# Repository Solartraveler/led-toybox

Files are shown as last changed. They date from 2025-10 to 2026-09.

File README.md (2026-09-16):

# LED Spiel

## Idea

Add some RGB LEDs in a box with sound. Fun for kids.

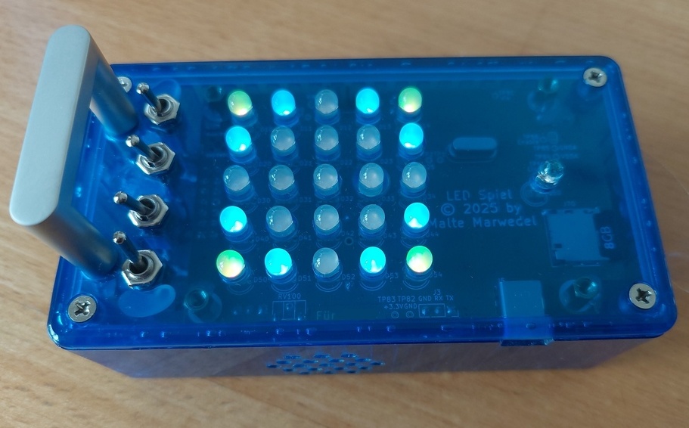
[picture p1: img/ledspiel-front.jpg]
Box in blue case


## Features

- 5x5 RGB LEDs

- Mono sound output

- Up to 7 inputs for buttons

- Measure brightness of environment to adjust LED brigtness

- IR receiver allows every remote control to become an extra toy

- Runs with two rechargeable NIMH AAA batteries. Non rechargeable ones work too.

- Slow charge over USB (~80mA). Can be disabled for non rechargeable batteries.

- SD card for storing sound (mp3 files) and LED sequences

- SD card file exchange and firmware upload over USB

- The STM32F405 MCU is fast enough for mp3 decoding

- Costs for all parts is ~95€.

## Status

The PCB is soldered, the case is complete, the software for the toy works, but is incomplete.

Two push buttons are on the left side, if one is pressed during power up, the device enters DFU firmware download mode.

Four switches are there for selecting songs.

Some animations are available.

Missing featues:

- Data exchange over USB mass storage is slow

- The IR receiver is currently unused.

## History

Planning...

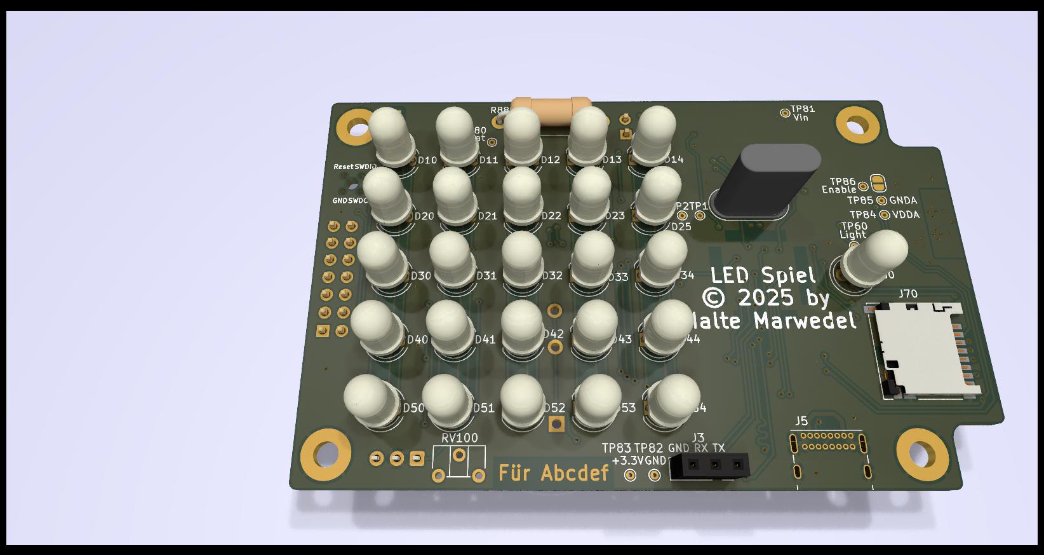
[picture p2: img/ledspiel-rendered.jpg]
PCB rendered


Soldering and debugging...

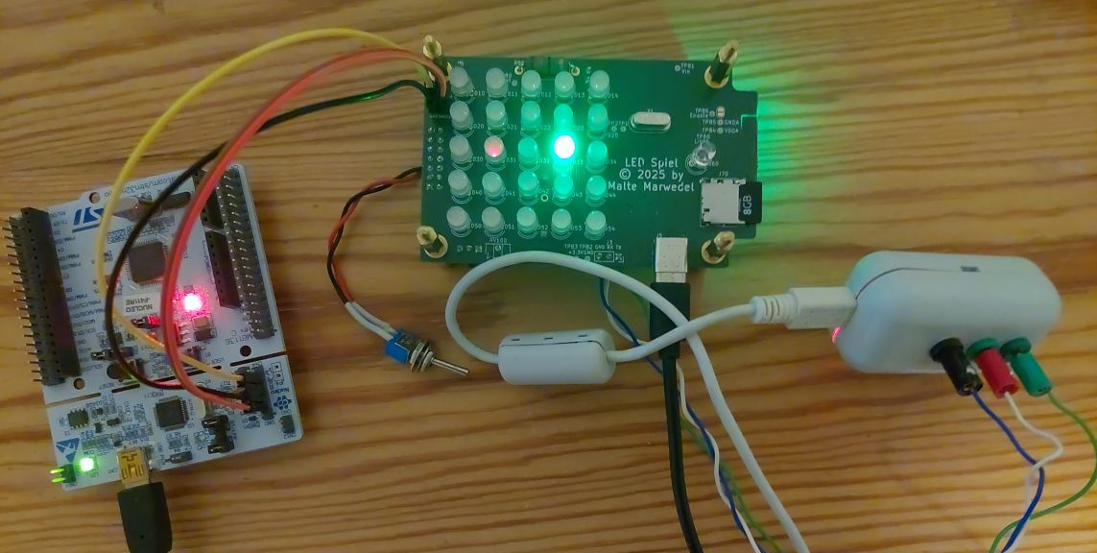
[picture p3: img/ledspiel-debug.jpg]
PCB with debug connection


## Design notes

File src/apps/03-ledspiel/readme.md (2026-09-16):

The ledspiel firmware

Implements USB mass storage if connected to USB.
Otherwise its an mp3 player with funny light effects.

The USB mass storage is a modified copy of
[06-usb-mass-storage](https://github.com/Solartraveler/UniversalboxArm/tree/a2017e5d17217898de555d77526e7ae967745359/src/apps/06-usb-mass-storage)

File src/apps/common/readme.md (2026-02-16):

# Shared files for the ARM processor #

## algorithm ##

Useful platform independend algorithm by the author of this project.

Files taken from [UniversalboxARM](https://github.com/Solartraveler/UniversalboxArm/tree/a2017e5d17217898de555d77526e7ae967745359/src/common/algorithm) commit #a2017e5d17217898de555d77526e7ae967745359.

License: BSD 3-Clause

## CMSIS ##
CMSIS header files from ARM and ST

License: Apache 2.0

Taken from STM32Cube_FW_F4_V1.28.3

and

STM32Cube_FW_F4_V1.25.2

# fatfs #
Fat filesystem from (http://elm-chan.org/fsw/ff/00index_e.html) version 0.14b.

License: BSD 1-Clause

# jsmn
Json parser from (https://github.com/zserge/jsmn) version 1.1.0

License: MIT

# ledspiellib

Files from the author of this project

Files are simply copied from [UniversalboxARM](https://github.com/Solartraveler/UniversalboxArm/tree/a2017e5d17217898de555d77526e7ae967745359/src/apps/common/boxlib) commit #a2017e5d17217898de555d77526e7ae967745359.
And where needed adapted to the STM32F405 and LedSpiel PCB pin connections.

License: BSD 3-Clause

# libmad
Libmad - MPEG audio decoder library

License: GPL v2 or newer

Taken from GIT [version 0.16.4 commit ee7c3cdd4361b7f7c7da52fa3ba9f76cc35230a9](https://codeberg.org/tenacityteam/libmad/releases/tag/0.16.4)

# lwip
Just for md5sum calculation.

Files taken from [LwIP](https://savannah.nongnu.org/projects/lwip/) version 2.1.3.

License: BSD 3-Clause

## shared-init
Most files are from ST. Linker scripts and init assembly routines.

License: Apache 2.0 and BSD 3-Clause

appInterface.h, stm32f4xx_hal_msp.c, system_stm32f4xx.c, and main.c are taken from
[UniversalboxARM](https://github.com/Solartraveler/UniversalboxArm/blob/a2017e5d17217898de555d77526e7ae967745359/src/apps/common/shared-init/) commit #a2017e5d17217898de555d77526e7ae967745359.

stm32f405-LedSpielV1/main.h is a modified file taken from
[UniversalboxARM](https://github.com/Solartraveler/UniversalboxArm/blob/a2017e5d17217898de555d77526e7ae967745359/src/apps/common/shared-init/stm32f411-nucleo/main.h) commit #a2017e5d17217898de555d77526e7ae967745359.
The modification is mostly CubeMX generated.

stm32f405-LedSpielV1/stm32f4xx_hal_conf.h is taken from
[UniversalboxARM](https://github.com/Solartraveler/UniversalboxArm/blob/a2017e5d17217898de555d77526e7ae967745359/src/apps/common/shared-init/stm32f411-nucleo/stm32f4xx_hal_conf.h) commit #a2017e5d17217898de555d77526e7ae967745359.

## stm32f4xx_HAL_Driver ##
Files from ST.

License: BSD 3-Clause

Taken from STM32Cube_FW_F4_V1.28.3

## libusb_stm32 ##
Usb communication library

License: Apache 2.0

Most files (but one) are taken from
[Libusb_stm32](https://github.com/dmitrystu/libusb_stm32) commit #396c2c50ad330b522104d0565525a7350e486fb9

The stm32_compat.h file is based on:
[stm32h](https://github.com/dmitrystu/stm32h/blob/7e854b1938c6ba5b4163b08de7842e406b5c5fcb/stm32.h) commit #7e854b1938c6ba5b4163b08de7842e406b5c5fcb

License: MIT

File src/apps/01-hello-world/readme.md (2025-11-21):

A simple function test

Prints a message over the UART and let some LEDs flash some patterns.

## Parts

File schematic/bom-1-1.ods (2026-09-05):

BOM LED Spiel | Version 1.1
ID | Name | Number | Reichelt Order No | TME Order No | Price | Sum Price | Notes | 3.1V Low voltage variant (should save ~10% consumption)
C1, C2, C71, | 22pF Unpolarized capacitor | 3 | NPO-G0805 22P |  | 0.02 € | 0.06 €
C3, C4, | 10pF Unpolarized capacitor | 2 | NPO-G0805 10P |  | 0.02 € | 0.04 € | C3 and C4 are only required if Y2 is equipped
C60, C70, C81, C86, C87, C92, C93, C101, C102, | 2.2µF Unpolarized capacitor | 9 | GRM21BR71E225K |  | 0.03 € | 0.27 €
C80, C82, C83, C84, | 10µF Unpolarized capacitor | 4 | GRM21BZ71E106K |  | 0.11 € | 0.44 €
C85, C88, C89, C90, C91, C100, | 100nF Unpolarized capacitor | 6 | KEM X7R0805 100N |  | 0.02 € | 0.12 €
C103, | 18nF Unpolarized capacitor | 1 | WAL 0805B183K500 |  | 0.04 € | 0.04 € | Optional
D10, D11, D12, D13, D14, D20, D21, D22, D23, D25, D30, D31, D32, D33, D34, D40, D41, D42, D43, D44, D50, D51, D52, D53, D54, | LED_RKBG RGB LED, red/cathode/blue/green | 25 | KBT L-154A4SURKQ |  | 0.80 € | 20.00 €
D80, D82, | SK14 Schottky diode | 2 | SK 14 DIO |  | 0.05 € | 0.10 €
D81, D83 | LED Light emitting diode green | 2 | 0805G3C-KHC-B |  | 0.19 € | 0.38 € | Actually any preferred color, red, green or blue can be used
D85, | LED Light emitting diode red | 1 | LS R976 |  | 0.04 € | 0.04 € | Actually any preferred color, red, green or blue can be used
D84, | BAT54C Schottky diode | 1 | BAT 54C SMD |  | 0.03 € | 0.03 €
F80, | 250mA Fuse | 1 | SMD-HASF 0,25A |  | 1.10 € | 1.10 € | Might be increased to 500mA depending on real consumption
J1, | Keys Generic connector, double row, 02x07, odd/even pin numbering scheme (row 1 odd numbers, row 2 even numbers), script generated (kicad-library-utils/schlib/autogen/connector/) | 1 | SL 2X10G 2,54 |  | 0.13 € | 0.13 €
J2, | SWD Debug Harwin M20-7810245 | 1 | --- | --- |  | 0.00 € | Optional
J3, | USART Debug Generic connector, single row, 01x03, script generated (kicad-library-utils/schlib/autogen/connector/) | 1 | MPE 094-1-003 |  | 0.14 € | 0.14 €
J5, | USB_C_Receptacle_USB2.0 USB 2.0-only Type-C Receptacle connector | 1 | --- | USB4085-GF-A | 0.88 € | 0.88 €
J70, | Micro_SD_Card_Det Micro SD Card Socket with card detection pins | 1 | --- | DM3D-SF/C | 1.90 € | 1.90 €
J80, JP1 | Battery Generic connector, Recharge Jumper, single row, 01x02, break off from J1 | 0 | SL 2X10G 2,54 |  | 0.13 € | 0.00 €
JP1, | Jumper | 1 | JUMPER 2,54 SW |  | 0.02 € | 0.02 €
L1, | 4.7µH Inductor, 1.5A | 1 | L-PISG 4,7µ |  | 0.99 € | 0.99 €
L2, | 1µH Inductor, 370mA | 1 | L-1008AS 1,0µ |  | 0.25 € | 0.25 €
LS100, | Speaker 0.2W (0.3W peak), 155070 | 1 | AL-30P |  | 2.89 € | 2.89 € | With the testpin TP100, the 0.1W AL23-P variant can be used as alternative
Q10, Q11, Q12, Q13, Q14, Q80, Q82, | BSS138 50V Vds, 0.22A Id, N-Channel MOSFET, SOT-23 | 7 | BSS 138P NXP |  | 0.06 € | 0.42 €
Q60, | SFH300-3/4 NPN phototransistor, collector/emitter | 1 | SFH 300-3/4 |  | 0.29 € | 0.29 €
Q70, Q81, | IRLML6402 -3.7A Id, -20V Vds, 65mOhm Rds, P-Channel HEXFET Power MOSFET, SOT-23 | 2 | IRLML 6402 |  | 0.20 € | 0.40 €
R1, R80 | 100kΩ Resistor | 2 | SMD-0805 100K |  | 0.03 € | 0.06 €
R2, R3, | 5.1kΩ Resistor 0603 | 2 | VIS CRCW06035K1 |  | 0.06 € | 0.12 €
R4, R5, R8, R9, R71, R82, R83, R89, R100, | 330kΩ Resistor | 9 | SMD-0805 330K |  | 0.03 € | 0.27 €
R11, R14, R17, R20, R23, | 470Ω Resistor | 5 | SMD-0805 470 |  | 0.03 € | 0.15 € |  | 330Ω Resistors
R10, R13, R16, R19, R22, R87, R90, R101 | 4.7kΩ Resistor | 8 | SMD-0805 4,70K |  | 0.03 € | 0.24 € |  | R10, R13, R16, R19, R22 = 3.9kΩ Resistors
R12, R15, R18, R21, R24, | 560Ω Resistor | 5 | SMD-0805 560 |  | 0.03 € | 0.15 € |  | 470Ω Resistors
R30, R31, R32, R33, R34, R60, R70, R91, R102, R110, R111, R112, R113, R114, R115, R116, | 220Ω Resistor | 16 | SMD-0805 220 |  | 0.02 € | 0.24 €
R61, | 1MΩ Resistor | 1 | SMD-0805 1,00M |  | 0.03 € | 0.03 €
R62, | 1kΩ Resistor | 1 | SMD-0805 1,00K |  | 0.03 € | 0.03 €
R63, R72, R103 | 56kΩ Resistor | 3 | SMD-0805 56,0K |  | 0.03 € | 0.09 €
R73, R74, R75, | 47Ω Resistor | 3 | SMD-0805 47,0 |  | 0.03 € | 0.09 €
R84, | 470kΩ Resistor | 1 | SMD-0805 470K |  | 0.03 € | 0.03 €
R85, | 270kΩ Resistor | 1 | SMD-0805 270K |  | 0.03 € | 0.03 € |  | 300kΩ Resistor
R88, | 12Ω Resistor, 2W | 1 | 2W METALL 12 |  | 0.13 € | 0.13 €
RV100, | 10kΩ Potentiometer | 1 | PT 6-S 10K |  | 0.44 € | 0.44 € | Optional, or use a 25K variant. If not used, close JP102 and adjust R101 to the desired volume
U1, | STM32F405RGTx ARM Cortex-M4 MCU, 1024KB flash, 128KB RAM, 168MHz, 1.8-3.6V, 51 GPIO, LQFP-64 | 1 | STM32F405RGT6 |  | 3.90 € | 3.90 €
U2, | USBLC6-2SC6 Very low capacitance ESD protection diode, 2 data-line, SOT-23-6 | 1 | USBLC6-2SC6 |  | 0.25 € | 0.25 €
U60, | TSOP382xx Photo Modules for PCM Remote Control Systems | 1 | TSOP 38238 |  | 0.50 € | 0.50 €
U80, | MCP1640CH Synchronous Boost Regulator, Adjustable Output 2.0V-5.5V, PWM/PFM True Disconnect, SOT-23 | 1 | MCP 1640T-I/CHY |  | 1.14 € | 1.14 € | Or MCP1640BT-I/CHY variant to have a higher consumption but less noise in the speaker
U81, | MCP1703, 3.3V 250mA Regulator, SOT-89 | 1 | MCP 1703-3302MB |  | 0.85 € | 0.85 €
U100, | LM4861 Boomer Mono 1.1W Audio Power Amplifier with Shutdown Mode | 1 | LM 4861 M |  | 1.84 € | 1.84 €
Y1, | 8MHz Two pin crystal | 1 | 8,0000-HC49U-S |  | 0.25 € | 0.25 €
Y2, | 32768Hz Two pin crystal | 1 | 0,032768-SMD |  | 0.61 € | 0.61 € | Optional
Case | Hammond 65x120x36 transparent/red/ blue polycarbonate | 1 | 1591CTBU | HM-1591CTCL | 9.00 € | 9.00 €
Batteries | 1/2 of a 4er NIMH AAA 850mAh pack | 0.5 | REC 850 4AAA |  | 9.80 € | 4.90 €
Batterie holder | 2x AAA | 1 | HALTER 2XUM4-NLF |  | 0.48 € | 0.48 €
MicroSD card | 8GB Intenso | 1 | INTENSO 3413460 |  | 2.95 € | 2.95 €
Keys Toggle |  | 4 | GOOBAY 10013 |  | 0.60 € | 2.40 €
Keys Push |  | 2 | DELOCK 20983 |  | 6.69 € | 13.38 €
On/Off switch |  | 1 | WS R13-112 AAAA |  | 1.05 € | 1.05 €
Wires | Cut in the middle to get two, so one cable per button (6), and one for power supply (1) -> 7 | 4 | DEBO DUPON 2PIN |  | 0.31 € | 1.24 €
PCB | 1/3 of a 2-Layer high density service from Aisler | 0.3333 |  |  | 30.00 € | 10.00 €
Handlebar | https://toom.de/p/moebelgriff-vernickelt-matt/7633681 | 1 |  |  | 4.99 € | 4.99 €
Sum |  |  |  |  |  | 92.76 €

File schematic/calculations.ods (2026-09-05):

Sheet: USB
Lengths | DP (in mm) | DM (in mm)
To STM | 26.1 | 27.6
To Connector | 11.2 | 9.63
Sum | 37,3 | 37,23
Delta | 0,0699999999999932

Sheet: C71
Power limiting, when switching on the SD card
See On Semi application note AND9093/D
Cload | 0.0000023 | F
Inrush | 10 | A
R1 | 200 | Ohm
R2 | 330000 | Ohm
Vin | 3.3 | V
Vth | 0.55 | V
Iload | 0 | A
gfs | 1
Result
Vpl | 0.55 | V
C1 | 4.42788333333333E-09 | F
->C71 should be at least 4.4pF

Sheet: LEDs
Default Vcc | 3.3 | V
LED color | Red | Green | Blue
Resistor | 560 | 4700 | 470 | Ohm
Resistor voltage | 1.433 | 0.933 | 0.548 | V
Current | 0.00255892857142857 | 0.000198510638297872 | 0.00116595744680851 | A
Sum per LED |  |  | 0.00392339665653495 | A
Sum per 5 LEDs |  |  | 0.0196169832826748 | A
Lower voltage (Vcc) | 3.1 | V
Delta to default Vcc | 0.2 | V
Resistor voltage | 1.233 | 0.733 | 0.348 | V
New resistor | 481.842288904397 | 3692.4973204716 | 298.467153284672 | Ohm
Cheap resistors | 470 | 3900 | 330 | Ohm

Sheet: L2
Inductivity | 0.000001 | H
Capacity | 0.00001 | F
Resonance | 50330.70 | Hz

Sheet: R88
 | Min | Max
U in | 3 | 3.3 | V
U battery full | 2.7 | 2.7 | V
U battery empty | 1.6 | 1.6 | V
U battery short circuit | 0 | 0 | V
Resistor | 12 | 12 | Ohm
Charging current full | 0.025 | 0.05 | A
Charging current empty | 0.116666666666667 | 0.141666666666667 | A
Currnt short circuit | 0.25 | 0.275 | A
Power R88 short circuit | 0.75 | 0.9075 | W

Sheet: Power estimate
Voltage | 3.3 | V
STM32F4 @ 60MHz | 0.022 | A
LEDs all on with multiplexing | 0.02 | A
SD card | 0.02 | A | 100mA peak
Audio amplifier | 0.0047 | A
Audio speaker max | 0.158113883008419 | A | 0.2 | W | 8 | Ohm | 1.26491106406735 | V
Sum | 0.224813883008419 | A | Maximum supported by MCP 1640 |  | 0.3 | A
Power | 0.741885813927783 | W
Step up efficiency | 0.85
Input Power | 0.872806839915038 | W
Input voltage | 2.1 | V
Input current | 0.415622304721447 | A

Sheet: Audio
Datasheet | Schematic
Vdd | Avcc | 3.3 | V
 | R101 | 4700 | Ohm
 | RV100 min | 0 | Ohm
 | RV100 max | 10000 | Ohm
Rf min |  | 4700 | Ohm
Rf max |  | 14700 | Ohm
R_i | R103 | 56000 | Ohm
R_L | LS100 | 8 | Ohm
C_i | C102 | 0.0000022 | F
C_B | C101 | 0.0000022 | F
C_f |  | 0 | F | Not needed as long as gain is lower than 10
P_O | LS100 | 0.2 | W | Speaker power rating
Caclculations according to the datasheet:
fc high pass |  | 1.29188017139633 | Hz | High pass filter
Gain min |  | 0.167857142857143
Gain max |  | 0.525
P_DMAX |  | 0.275951027586893 | W
V_opeak |  | 1.78885438199983 | V
V_OD |  | 0.6 | V
V_dd_min |  | 2.38885438199983 | V
Own calculations:
V_out_min |  | 0,553928571428571 | V
V_out_max |  | 1,7325 | V | Should be close to V_opeak
P_O_min |  | 0.0191773038903061 | W
P_O_max |  | 0.187597265625 | W | Should not be much higher than P_O

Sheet: StepUp
Normal voltage
R84 | 470000 | Ohm
R85 | 270000 | Ohm
FB | 1.21 | V
Uout | 3.3162962962963 | V
Low voltage
R84 | 470000 | Ohm
R85 | 300000 | Ohm
FB | 1.21 | V
Uout | 3.10566666666667 | V

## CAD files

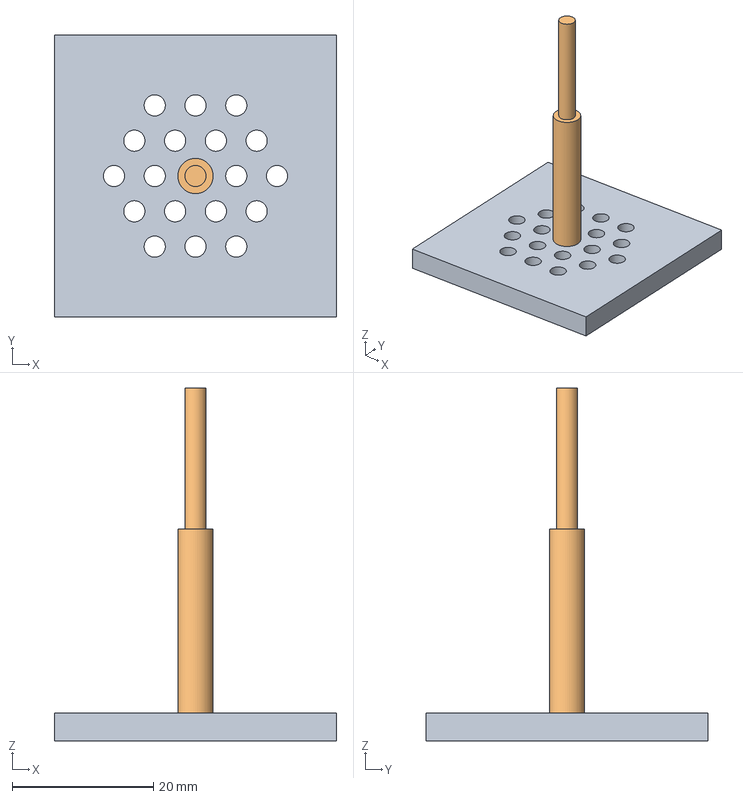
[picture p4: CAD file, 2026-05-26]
case/speaker-drill-v1.FCStd
40.0 x 40.0 x 50.0 mm
Endmill

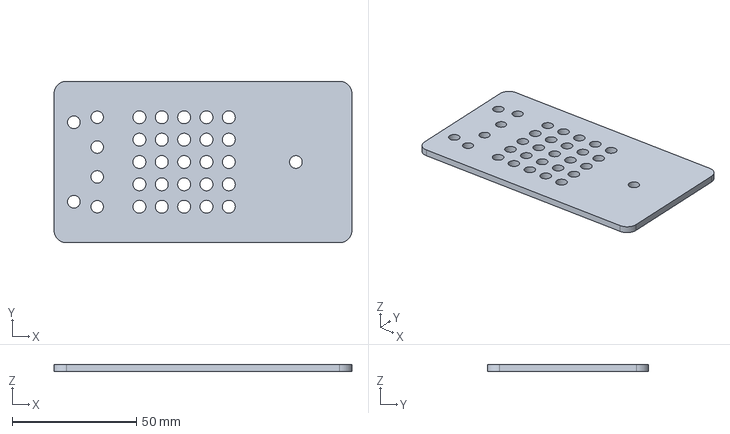
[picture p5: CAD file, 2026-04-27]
case/top-drill-v1.FCStd
120.0 x 65.0 x 3.00 mm

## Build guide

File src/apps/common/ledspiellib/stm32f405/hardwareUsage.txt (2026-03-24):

Shared sources:

timer32Bit:    TIM2
rs232debug:    USART1, USART1_IRQHandler
stackSampler:  TIM10
flash:         DMA2 Stream 2, DMA2 Stream 3, SPI1
ledMatrix:     TIM1, TIM8, DMA2 Stream 1, DMA2 Stream 5
audioOut:      TIM7, DAC1, DMA1 Stream 2

Projects:

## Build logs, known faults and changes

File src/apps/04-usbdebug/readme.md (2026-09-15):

# The original USB implementation has troubles with bulk transfers. This program is here to help fixing the lib

It opens two bulk endpoints. Each incoming packet is "processed" by the main loop and then send back
over the outgoing endpoint. The first byte of each packet is printed on the serial port.
This is much slower than USB and therefore makes at some point NAK to the incoming endpoint necessary.

## Key findings of the original lib

### Not leaving the loop in usbd_stm32f429_otgfs.c evt_poll

If USB with ISR is used, the callback for incoming packets must read them
from the hardware FIFO, otherwise the loop in evt_poll is never left.
But reading without loosig data is impossible if these can not be processed
as fast as USB can transfer them and a NAK on the endpoint is needed.
So the callback must notify this to the loop to terminate in such a case.
But then two new issues arise:

1. The lvl status may not generate an ISR anylonger, otherwise the ISR is
immediately re-enterd. And the main loop can not process the data at all.

2. If USBD_SOF_DISABLED is not set, every SOF ISR again checks the RXFLVL signal
and the loop skips the part clearing the SOF ISR and as result again the ISR
is immediately re-enterd.

### Configuring an endpoint may only be done if it was deconfigured before

If usbd_ep_config for an endpoint was called, it may not be called a second
time, because every call allocates another 64 bytes of the 1280 maximum buffer.
As result having 2 endpoints (64 bytes each), this fails at the 20th call.

And every opening by a user application on the host does a set config.

## Testing this project

Give the userspace access to the device by copying 55-testdevice5.rules to /etc/udev/rules.d/

Then

udevadm control --reload-rules

udevadm trigger --subsystem-match=usb

Call ./testbulk.py 178 64 to see if the USB bulk endpoint is working as expected.
Without the issues above fixed, sending more than USB_BULK_QUEUE_FROMHOST_LEN = 50
packets might result in errors.
After fixing the issues, sending more than (USB_BULK_QUEUE_FROMHOST_LEN + USB_BULK_QUEUE_TOHOST_LEN) = 178 packets might result in errors.
Actually most of the time ~5 more packets will work due to some processing or host side queueing.
The debug message "Re-enabled RX ISR" should be seen.

./testbulkreset.py resets the current FIFO index back to 0.

## Debugging

1. Connect a STM32 Nucleo to the target

2. Connect openocd
cp /usr/share/openocd/scripts/target/stm32f4x.cfg stm32f4x-slow.cfg
Replace all values behing 'adapter speed' by 400 (three times in the file).
openocd -f /usr/share/openocd/scripts/interface/stlink.cfg -f stm32f4x-slow.cfg

3. In another console connect with gdb
Use the ram.elf if uploaded temporary by my DFU bootloader, use the flash.elf if the ST bootloader has been used.
gdb-multiarch build/stm32f405xx-LedSpielV1/UsbDebug-stm32f405xx-ram.elf -ex "target remote localhost:3333"

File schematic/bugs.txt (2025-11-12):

Based on commit 3cc726cd5dc6b (tag: SendToPcBManufacturer) the following bugs are in the schematic and PCB layout (revision 1.0):

1. Pins for RGB LEDs are wrong
  The wrong footprint results in the green and blue LED pins to be switched.
  Workaround: Switch pins in software, switch resistor values for this colors. No PCB changes required.
  Schematic and PCB adjusted in revision 1.1

2. PowerOff signal is connected to JTAG JTDI pin and has an internal pull-up
  Beside no documentation has been found describing this behaviour, a high value can be measured on
  powerup for some microseconds. This would switch off the power supply immediately.
  Workaround: Decrease R8 to a value where the internal STM32 pull-up and R8 does not generate a voltage large enough
  for Q80 to open. 4.7kΩ will do. No PCB changes required.
  Schematic and PCB adjusted in revision 1.1

3. RV100 and J3 should be soldered from the bottom
  This allows to save height space in the case.
  Soldering from the bottom does not need any layout changes, however then the silk screen will be on the wrong side.
  No schematic and PCB adjustments are planned, as this not really an error.

4. RTC might have a wrong frequency due to an errata of the STM32F405
  According to the errata, the LSI might be wrong when PC13 toggles. PC13 is used to control the charger.
  No change planned - this pin is not toggled often and the RTC is optional and currently no usage is planned.

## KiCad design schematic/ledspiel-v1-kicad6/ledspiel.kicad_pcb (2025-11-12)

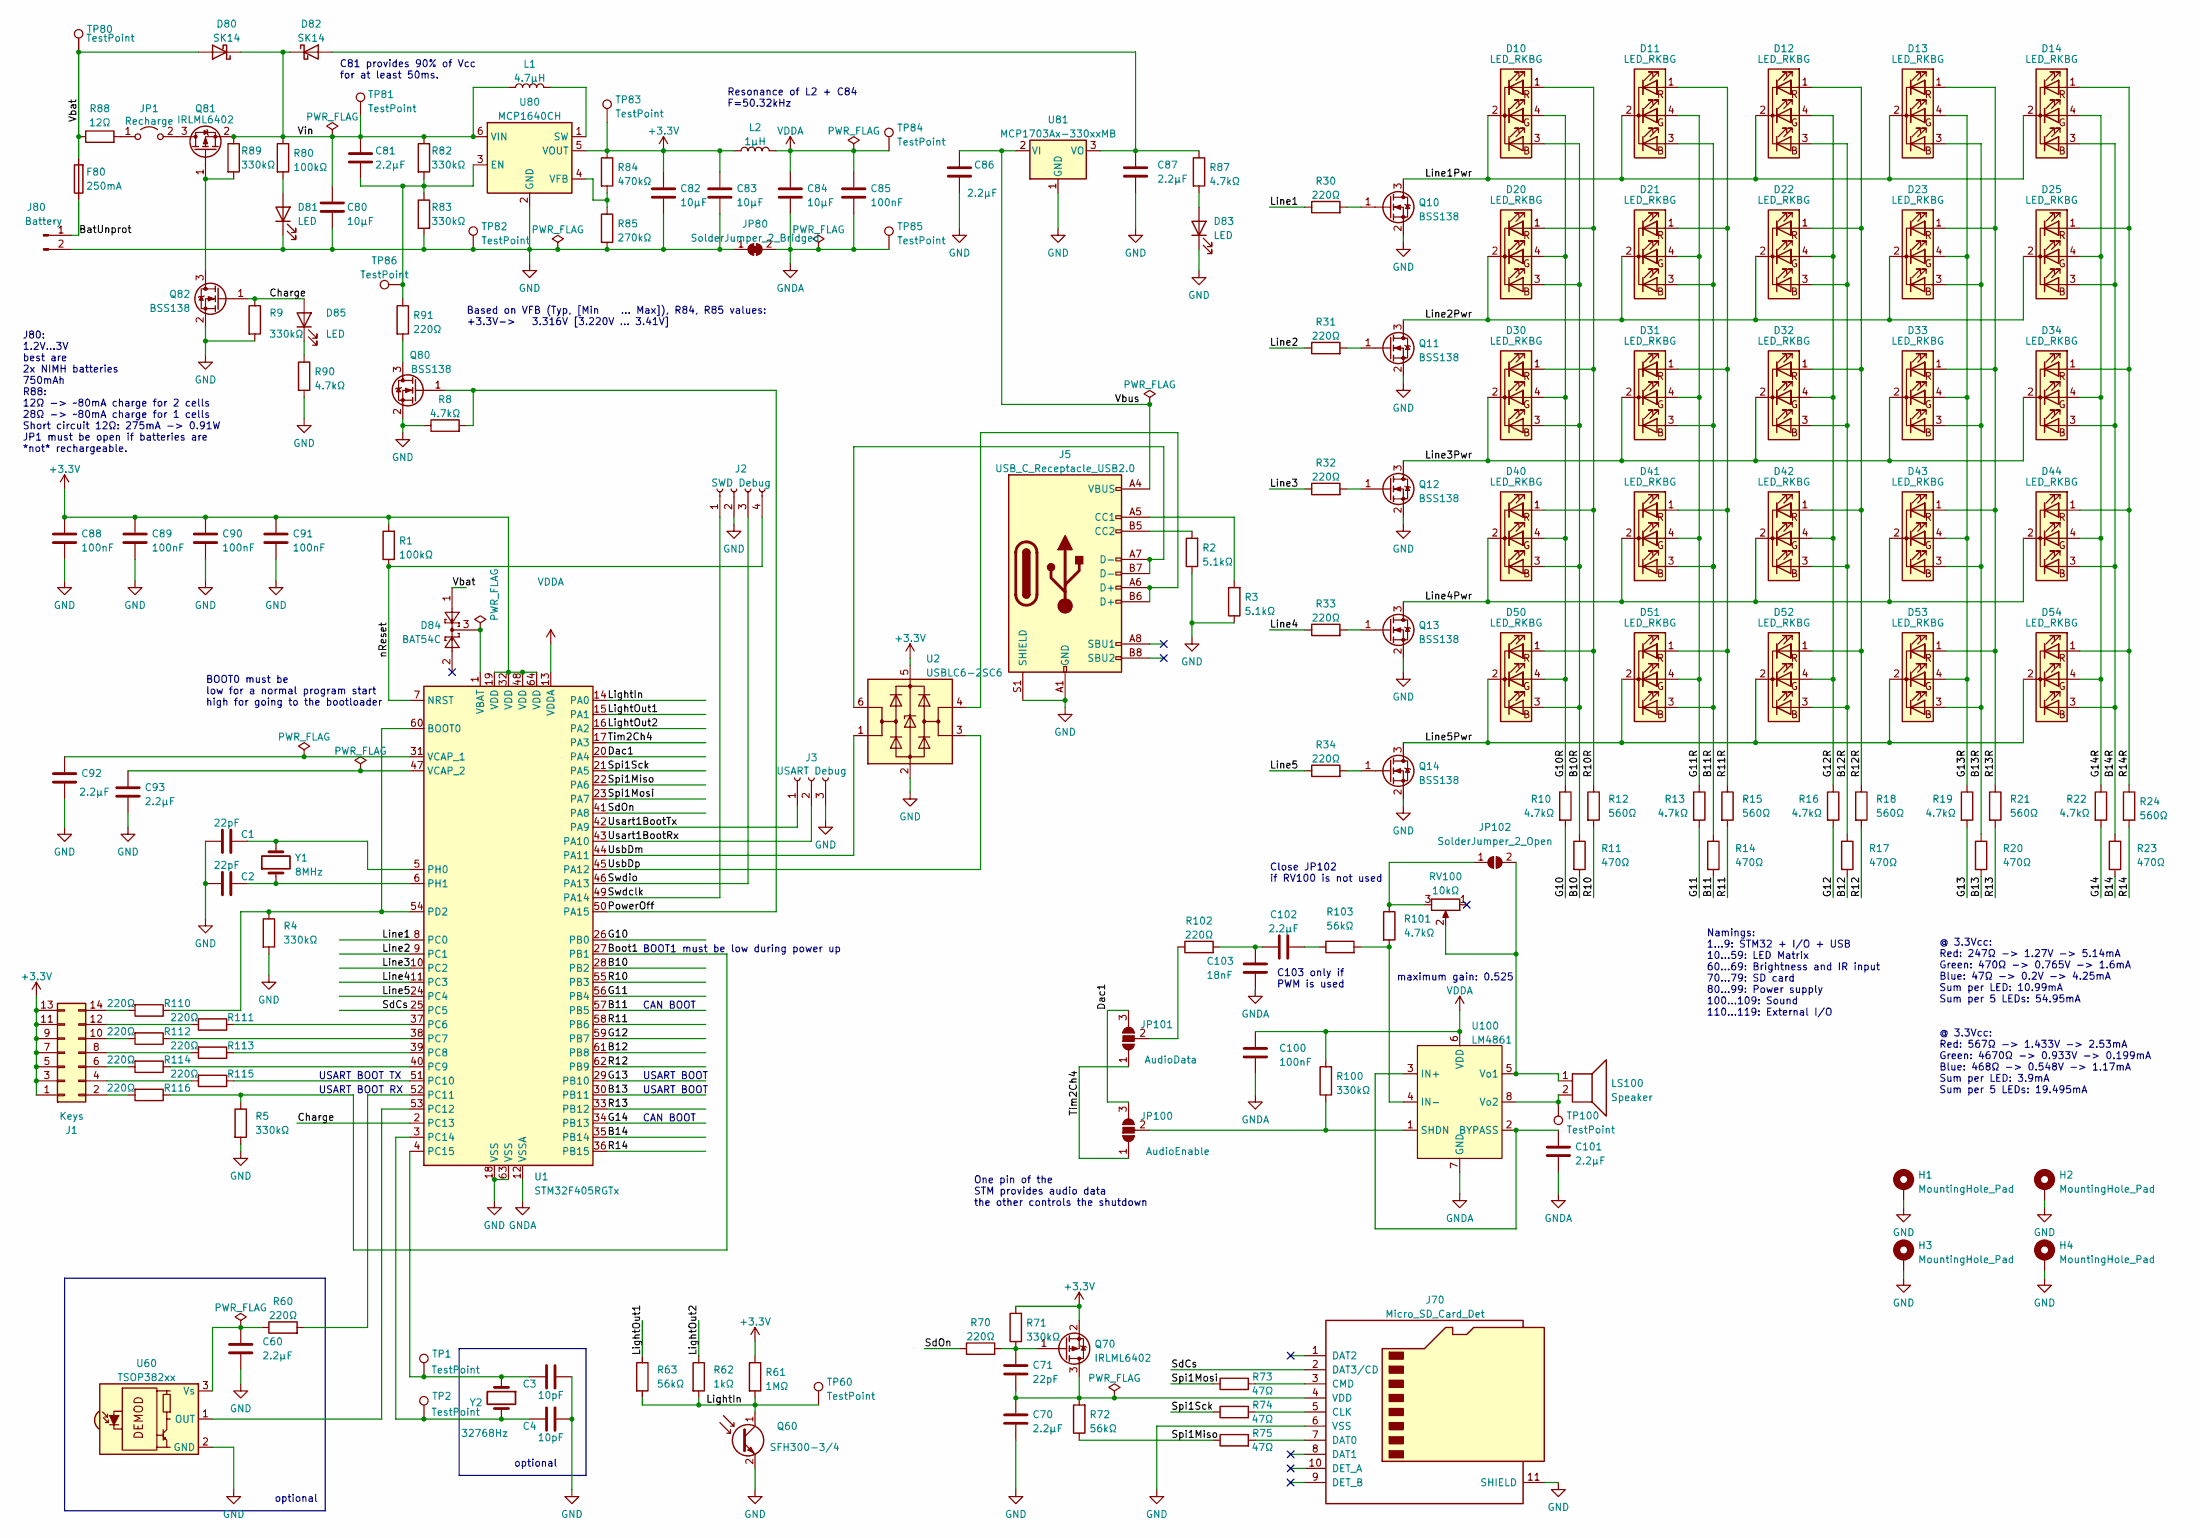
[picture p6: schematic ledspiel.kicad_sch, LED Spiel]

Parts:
C1, C2, C71: 22pF; C_0805_2012Metric_Pad1.18x1.45mm_HandSolder
C3, C4: 10pF; C_0805_2012Metric_Pad1.18x1.45mm_HandSolder
C60, C70, C81, C86, C87, C92, C93, C101, C102: 2.2µF; C_0805_2012Metric_Pad1.18x1.45mm_HandSolder
C80, C82, C83, C84: 10µF; C_0805_2012Metric_Pad1.18x1.45mm_HandSolder
C85, C88, C89, C90, C91, C100: 100nF; C_0805_2012Metric_Pad1.18x1.45mm_HandSolder
C103: 18nF; C_0805_2012Metric_Pad1.18x1.45mm_HandSolder
D10, D11, D12, D13, D14, D20, D21, D22, D23, D25, D30, D31, D32, D33, D34, D40, D41, D42, D43, D44, D50, D51, D52, D53, D54: LED_RKBG; LED_D5.0mm-4_RGB
D80, D82: SK14; D_SMB_Handsoldering
D81, D83, D85: LED; LED_0805_2012Metric_Pad1.15x1.40mm_HandSolder
D84: BAT54C; SOT-23
F80: 250mA; SFM_OMNI-BLOK_Handsolder
H1, H2, H3, H4: MountingHole_Pad; MountingHole_3.2mm_M3_Pad
J1: Keys; PinHeader_2x07_P2.54mm_Vertical
J2: SWD Debug; Harwin_M20-7810245_2x02_P2.54mm_Vertical
J3: USART Debug; PinSocket_1x03_P2.54mm_Vertical
J5: USB_C_Receptacle_USB2.0; USB_C_Receptacle_GCT_USB4085
J70: Micro_SD_Card_Det; microSD_HC_Hirose_DM3D-SF
J80: Battery; PinHeader_1x02_P2.54mm_Vertical
JP1: Recharge; PinHeader_1x02_P2.54mm_Vertical
JP80: SolderJumper_2_Bridged; SolderJumper-2_P1.3mm_Bridged_RoundedPad1.0x1.5mm
JP100: AudioEnable; SolderJumper-3_P1.3mm_Open_RoundedPad1.0x1.5mm_NumberLabels
JP101: AudioData; SolderJumper-3_P1.3mm_Open_RoundedPad1.0x1.5mm_NumberLabels
JP102: SolderJumper_2_Open; SolderJumper-2_P1.3mm_Open_RoundedPad1.0x1.5mm
L1: 4.7µH; L_Fastron_PISG_Handsoldering
L2: 1µH; L_1008_2520Metric_Pad1.43x2.20mm_HandSolder
LS100: Speaker; Buzzer_D30mm_H11mm_P15mm
Q10, Q11, Q12, Q13, Q14, Q80, Q82: BSS138; SOT-23
Q60: SFH300-3/4; LED_D5.0mm_Clear
Q70, Q81: IRLML6402; SOT-23
R1, R80: 100kΩ; R_0805_2012Metric_Pad1.20x1.40mm_HandSolder
R2, R3: 5.1kΩ; R_0603_1608Metric_Pad0.98x0.95mm_HandSolder
R4, R5, R9, R71, R82, R83, R89, R100: 330kΩ; R_0805_2012Metric_Pad1.20x1.40mm_HandSolder
R8, R10, R13, R16, R19, R22, R87, R90, R101: 4.7kΩ; R_0805_2012Metric_Pad1.20x1.40mm_HandSolder
R11, R14, R17, R20, R23: 470Ω; R_0805_2012Metric_Pad1.20x1.40mm_HandSolder
R12, R15, R18, R21, R24: 560Ω; R_0805_2012Metric_Pad1.20x1.40mm_HandSolder
R30, R31, R32, R33, R34, R60, R70, R91, R102, R110, R111, R112, R113, R114, R115, R116: 220Ω; R_0805_2012Metric_Pad1.20x1.40mm_HandSolder
R61: 1MΩ; R_0805_2012Metric_Pad1.20x1.40mm_HandSolder
R62: 1kΩ; R_0805_2012Metric_Pad1.20x1.40mm_HandSolder
R63, R72, R103: 56kΩ; R_0805_2012Metric_Pad1.20x1.40mm_HandSolder
R73, R74, R75: 47Ω; R_0805_2012Metric_Pad1.20x1.40mm_HandSolder
R84: 470kΩ; R_0805_2012Metric_Pad1.20x1.40mm_HandSolder
R85: 270kΩ; R_0805_2012Metric_Pad1.20x1.40mm_HandSolder
R88: 12Ω; R_Axial_DIN0414_L11.9mm_D4.5mm_P15.24mm_Horizontal
RV100: 10kΩ; Potentiometer_Piher_PT-6-H_Horizontal
TP1, TP2, TP60, TP80, TP81, TP82, TP83, TP84, TP85, TP86: TestPoint; TestPoint_THTPad_D1.0mm_Drill0.5mm
TP100: TestPoint; TestPoint_THTPad_D2.0mm_Drill1.2mm
U1: STM32F405RGTx; LQFP-64_10x10mm_P0.5mm_Handsoldering
U2: USBLC6-2SC6; SOT-23-6_Handsoldering
U60: TSOP382xx; Vishay_MINICAST-3Pin
U80: MCP1640CH; SOT-23-6_Handsoldering
U81: MCP1703Ax-330xxMB; SOT-89-3
U100: LM4861; SOIC-8_3.9x4.9mm_P1.27mm
Y1: 8MHz; Crystal_HC49-U_Vertical
Y2: 32768Hz; Crystal_MP03

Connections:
+3.3V: C82.1, C83.1, C88.1, C89.1, C90.1, C91.1, J1.1, J1.3, J1.5, J1.7, J1.9, J1.11, J1.13, L2.1, Q70.2 (S), R1.2, R61.1, R71.2, R84.1, TP83.1, U1.19 (VDD), U1.32 (VDD), U1.48 (VDD), U1.64 (VDD), U2.5 (VBUS), U80.5 (VOUT)
/B10: R11.2, U1.28 (PB2)
/B10R: D10.3 (BA), D20.3 (BA), D30.3 (BA), D40.3 (BA), D50.3 (BA), R11.1
/B11: R14.2, U1.57 (PB5)
/B11R: D11.3 (BA), D21.3 (BA), D31.3 (BA), D41.3 (BA), D51.3 (BA), R14.1
/B12: R17.2, U1.61 (PB8)
/B12R: D12.3 (BA), D22.3 (BA), D32.3 (BA), D42.3 (BA), D52.3 (BA), R17.1
/B13: R20.2, U1.30 (PB11)
/B13R: D13.3 (BA), D23.3 (BA), D33.3 (BA), D43.3 (BA), D53.3 (BA), R20.1
/B14: R23.2, U1.35 (PB14)
/B14R: D14.3 (BA), D25.3 (BA), D34.3 (BA), D44.3 (BA), D54.3 (BA), R23.1
/BatUnprot: F80.1, J80.1
/Boot1: R5.1, R116.1, U1.27 (PB1)
/Charge: D85.2 (A), Q82.1 (G), R9.1, U1.2 (PC13)
/Dac1: JP100.3 (B), JP101.3 (B), U1.20 (PA4)
/G10: R10.2, U1.26 (PB0)
/G10R: D10.4 (GA), D20.4 (GA), D30.4 (GA), D40.4 (GA), D50.4 (GA), R10.1
/G11: R13.2, U1.56 (PB4)
/G11R: D11.4 (GA), D21.4 (GA), D31.4 (GA), D41.4 (GA), D51.4 (GA), R13.1
/G12: R16.2, U1.59 (PB7)
/G12R: D12.4 (GA), D22.4 (GA), D32.4 (GA), D42.4 (GA), D52.4 (GA), R16.1
/G13: R19.2, U1.29 (PB10)
/G13R: D13.4 (GA), D23.4 (GA), D33.4 (GA), D43.4 (GA), D53.4 (GA), R19.1
/G14: R22.2, U1.34 (PB13)
/G14R: D14.4 (GA), D25.4 (GA), D34.4 (GA), D44.4 (GA), D54.4 (GA), R22.1
/LightIn: Q60.1 (C), R61.2, R62.2, R63.2, TP60.1, U1.14 (PA0)
/LightOut1: R63.1, U1.15 (PA1)
/LightOut2: R62.1, U1.16 (PA2)
/Line1: R30.1, U1.8 (PC0)
/Line1Pwr: D10.2 (K), D11.2 (K), D12.2 (K), D13.2 (K), D14.2 (K), Q10.3 (D)
/Line2: R31.1, U1.9 (PC1)
/Line2Pwr: D20.2 (K), D21.2 (K), D22.2 (K), D23.2 (K), D25.2 (K), Q11.3 (D)
/Line3: R32.1, U1.10 (PC2)
/Line3Pwr: D30.2 (K), D31.2 (K), D32.2 (K), D33.2 (K), D34.2 (K), Q12.3 (D)
/Line4: R33.1, U1.11 (PC3)
/Line4Pwr: D40.2 (K), D41.2 (K), D42.2 (K), D43.2 (K), D44.2 (K), Q13.3 (D)
/Line5: R34.1, U1.24 (PC4)
/Line5Pwr: D50.2 (K), D51.2 (K), D52.2 (K), D53.2 (K), D54.2 (K), Q14.3 (D)
/PowerOff: Q80.1 (G), R8.2, U1.50 (PA15)
/R10: R12.2, U1.55 (PB3)
/R10R: D10.1 (RA), D20.1 (RA), D30.1 (RA), D40.1 (RA), D50.1 (RA), R12.1
/R11: R15.2, U1.58 (PB6)
/R11R: D11.1 (RA), D21.1 (RA), D31.1 (RA), D41.1 (RA), D51.1 (RA), R15.1
/R12: R18.2, U1.62 (PB9)
/R12R: D12.1 (RA), D22.1 (RA), D32.1 (RA), D42.1 (RA), D52.1 (RA), R18.1
/R13: R21.2, U1.33 (PB12)
/R13R: D13.1 (RA), D23.1 (RA), D33.1 (RA), D43.1 (RA), D53.1 (RA), R21.1
/R14: R24.2, U1.36 (PB15)
/R14R: D14.1 (RA), D25.1 (RA), D34.1 (RA), D44.1 (RA), D54.1 (RA), R24.1
/SdCs: J70.2 (DAT3/CD), U1.25 (PC5)
/SdOn: R70.1, U1.41 (PA8)
/Spi1Miso: R72.1, R75.1, U1.22 (PA6)
/Spi1Mosi: R73.1, U1.23 (PA7)
/Spi1Sck: R74.1, U1.21 (PA5)
/Swdclk: J2.1, U1.49 (PA14)
/Swdio: J2.3, U1.46 (PA13)
/Tim2Ch4: JP100.1 (A), JP101.1 (A), U1.17 (PA3)
/Usart1BootRx: J3.2, U1.43 (PA10)
/Usart1BootTx: J3.1, U1.42 (PA9)
/UsbDm: U1.44 (PA11), U2.1 (I/O1)
/UsbDp: U1.45 (PA12), U2.3 (I/O2)
/Vbat: D80.2 (A), D84.1, F80.2, R88.1, TP80.1
/Vbus: C86.1, J5.A4 (VBUS), J5.A9 (VBUS), J5.B4 (VBUS), J5.B9 (VBUS), U81.2 (VI)
/Vin: C80.1, C81.1, D80.1 (K), D82.1 (K), L1.1, Q81.2 (S), R80.1, R82.1, R89.1, TP81.1, U80.6 (VIN)
/nReset: J2.4, R1.1, U1.7 (NRST)
GND: C1.1, C2.1, C3.1, C4.1, C60.2, C70.2, C80.2, C82.2, C83.2, C86.2, C87.2, C88.2, C89.2, C90.2, C91.2, C92.2, C93.2, D81.1 (K), D83.1 (K), H1.1, H2.1, H3.1, H4.1, J2.2, J3.3, J5.A1 (GND), J5.A12 (GND), J5.B1 (GND), J5.B12 (GND), J5.S1 (SHIELD), J70.6 (VSS), J70.11 (SHIELD), J80.2, JP80.1 (A), Q10.2 (S), Q11.2 (S), Q12.2 (S), Q13.2 (S), Q14.2 (S), Q60.2 (E), Q80.2 (S), Q82.2 (S), R2.1, R3.1, R4.2, R5.2, R8.1, R9.2, R83.2, R85.2, R90.2, TP82.1, U1.18 (VSS), U1.63 (VSS), U2.2 (GND), U60.2 (GND), U80.2 (GND), U81.1 (GND)
GNDA: C84.2, C85.2, C100.2, C101.2, C103.2, JP80.2 (B), TP85.1, U1.12 (VSSA), U100.7 (GND)
unnamed: C1.2, U1.5 (PH0), Y1.2
unnamed: C2.2, U1.6 (PH1), Y1.1
unnamed: C3.2, TP1.1, U1.4 (PC15), Y2.1
unnamed: C4.2, TP2.1, U1.3 (PC14), Y2.2
unnamed: C60.1, R60.1, U60.3 (Vs)
unnamed: C70.1, C71.2, J70.4 (VDD), Q70.3 (D), R72.2
unnamed: C71.1, Q70.1 (G), R70.2, R71.1
unnamed: C81.2, R82.2, R83.1, R91.1, TP86.1, U80.3 (EN)
unnamed: C87.1, D82.2 (A), R87.1, U81.3 (VO)
unnamed: C92.1, U1.31 (VCAP_1)
unnamed: C93.1, U1.47 (VCAP_2)
unnamed: C101.1, U100.2 (BYPASS), U100.3 (IN+)
unnamed: C102.1, C103.1, R102.2
unnamed: C102.2, R103.1
unnamed: D81.2 (A), R80.2
unnamed: D83.2 (A), R87.2
unnamed: D84.3, U1.1 (VBAT)
unnamed: D85.1 (K), R90.1
unnamed: J1.2, R116.2
unnamed: J1.4, R115.2
unnamed: J1.6, R114.2
unnamed: J1.8, R113.2
unnamed: J1.10, R112.2
unnamed: J1.12, R111.2
unnamed: J1.14, R110.2
unnamed: J5.A5 (CC1), R3.2
unnamed: J5.A6 (D+), J5.B6 (D+), U2.4 (I/O2)
unnamed: J5.A7 (D-), J5.B7 (D-), U2.6 (I/O1)
unnamed: J5.B5 (CC2), R2.2
unnamed: J70.3 (CMD), R73.2
unnamed: J70.5 (CLK), R74.2
unnamed: J70.7 (DAT0), R75.2
unnamed: JP1.1 (A), R88.2
unnamed: JP1.2 (B), Q81.3 (D)
unnamed: JP100.2 (C), R100.1, U100.1 (SHDN)
unnamed: JP101.2 (C), R102.1
unnamed: JP102.1 (A), R101.1, RV100.3
unnamed: JP102.2 (B), LS100.1, RV100.2, U100.5 (Vo1)
unnamed: L1.2, U80.1 (SW)
unnamed: LS100.2, TP100.1, U100.8 (Vo2)
unnamed: Q10.1 (G), R30.2
unnamed: Q11.1 (G), R31.2
unnamed: Q12.1 (G), R32.2
unnamed: Q13.1 (G), R33.2
unnamed: Q14.1 (G), R34.2
unnamed: Q80.3 (D), R91.2
unnamed: Q81.1 (G), Q82.3 (D), R89.2
unnamed: R60.2, U1.52 (PC11)
unnamed: R84.2, R85.1, U80.4 (VFB)
unnamed: R101.2, R103.2, U100.4 (IN-)
unnamed: R4.1, R110.1, U1.54 (PD2), U1.60 (BOOT0)
unnamed: R111.1, U1.37 (PC6)
unnamed: R112.1, U1.38 (PC7)
unnamed: R113.1, U1.39 (PC8)
unnamed: R114.1, U1.40 (PC9)
unnamed: R115.1, U1.51 (PC10)
unnamed: U1.53 (PC12), U60.1 (OUT)
VDDA: C84.1, C85.1, C100.1, L2.2, R100.2, TP84.1, U1.13 (VDDA), U100.6 (VDD)

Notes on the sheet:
optional
BOOT1 must be low during power up
CAN BOOT
J80: 1.2V...3V best are 2x NIMH batteries 750mAh R88: 12Ω -> ~80mA charge for 2 cells 28Ω -> ~80mA charge for 1 cells Short circuit 12Ω: 275mA -> 0.91W JP1 must be open if batteries are *not* rechargeable.
USART BOOT TX
Based on VFB (Typ, [Min ... Max]), R84, R85 values: +3.3V-> 3.316V [3.220V ... 3.41V]
C81 provides 90% of Vcc for at least 50ms.
BOOT0 must be low for a normal program start high for going to the bootloader
One pin of the STM provides audio data the other controls the shutdown
@ 3.3Vcc: Red: 247Ω -> 1.27V -> 5.14mA Green: 470Ω -> 0.765V -> 1.6mA Blue: 47Ω -> 0.2V -> 4.25mA Sum per LED: 10.99mA Sum per 5 LEDs: 54.95mA @ 3.3Vcc: Red: 567Ω -> 1.433V -> 2.53mA Green: 4670Ω -> 0.933V -> 0.199mA Blue: 468Ω -> 0.548V -> 1.17mA Sum per LED: 3.9mA Sum per 5 LEDs: 19.495mA
Close JP102 if RV100 is not used
USART BOOT
USART BOOT RX
C103 only if PWM is used
Resonance of L2 + C84 F=50.32kHz
maximum gain: 0.525
Namings: 1...9: STM32 + I/O + USB 10...59: LED Matrix 60...69: Brightness and IR input 70...79: SD card 80...99: Power supply 100...109: Sound 110...119: External I/O

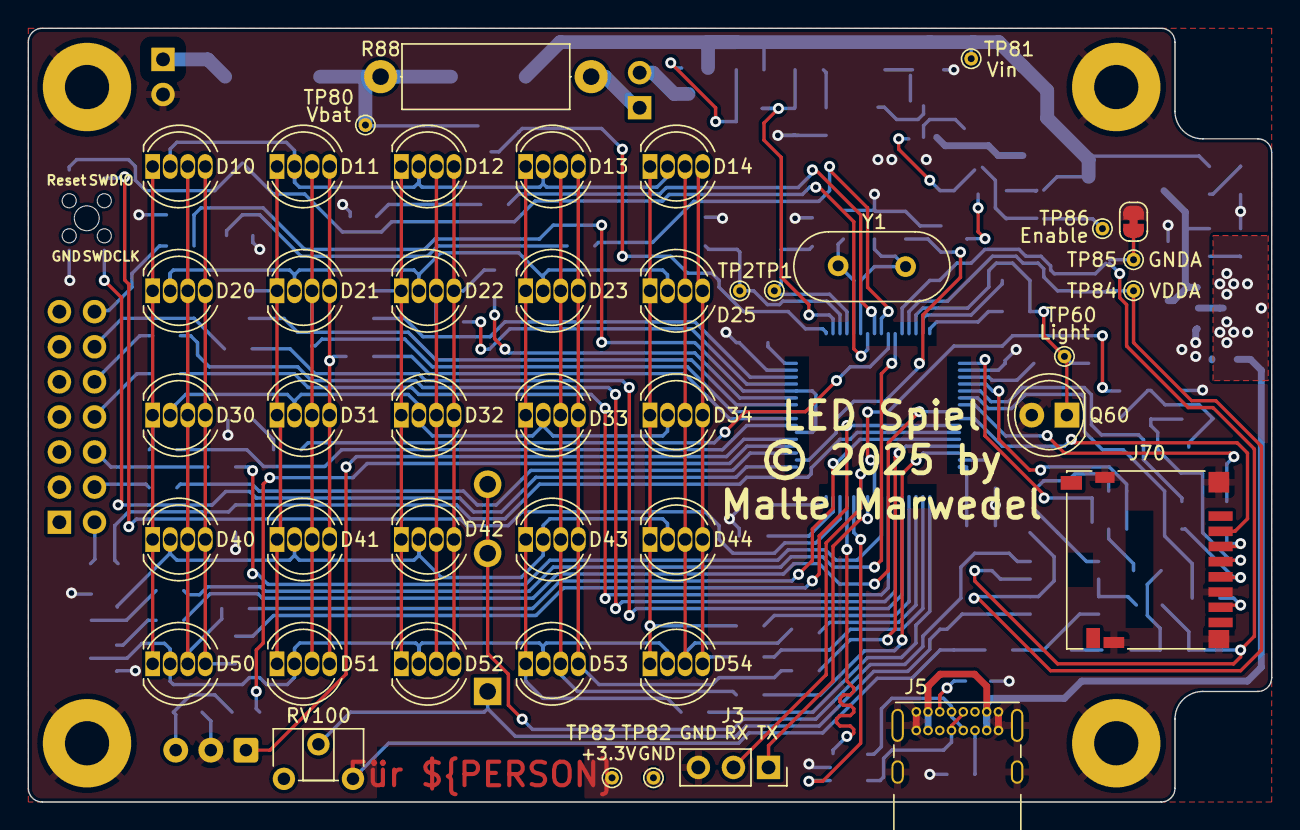
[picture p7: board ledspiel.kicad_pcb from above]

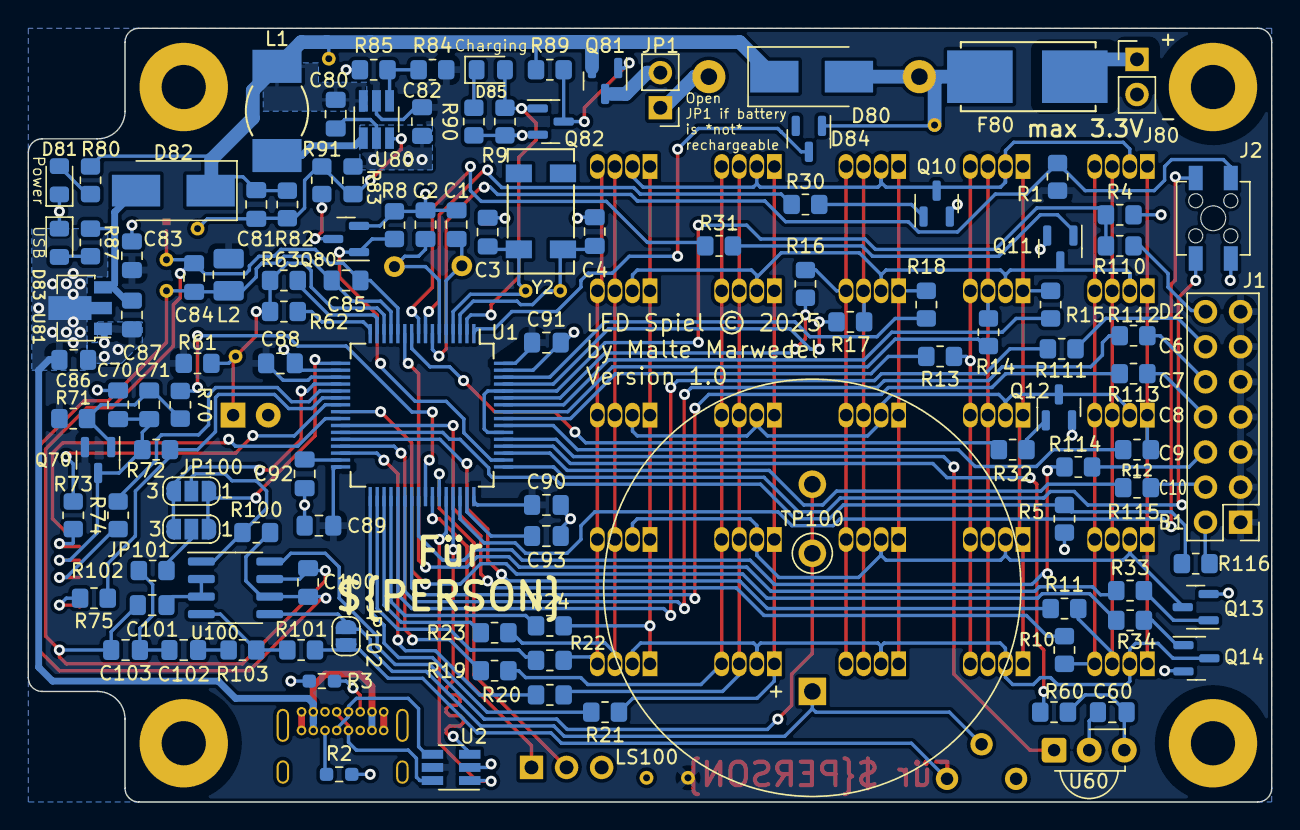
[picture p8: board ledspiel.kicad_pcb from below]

Board: 2 copper layers, 90.0 x 56.0 mm, 163 parts (116 on the bottom side), 125 nets.

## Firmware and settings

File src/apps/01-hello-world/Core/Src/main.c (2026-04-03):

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
/* Includes ------------------------------------------------------------------*/
#include "main.h"

/* USER CODE BEGIN Includes */

#include <math.h>
#include <stdarg.h>
#include <stdbool.h>
#include <string.h>
#include <stdio.h>

#include "sdmmcAccess.h"
#include "ledspiellib/ir.h"
#include "ledspiellib/mcu.h"
#include "ledspiellib/simpleadc.h"
#include "ledspiellib/spiGeneric.h"


/* USER CODE END Includes */

/* USER CODE BEGIN PD */

#define LED_R 1
#define LED_G 4
#define LED_B 2

#define F_CPU 64000000ULL

/* USER CODE END PD */

ADC_HandleTypeDef hadc1;

DAC_HandleTypeDef hdac;

RTC_HandleTypeDef hrtc;

SPI_HandleTypeDef hspi1;

TIM_HandleTypeDef htim1;

UART_HandleTypeDef huart1;

PCD_HandleTypeDef hpcd_USB_OTG_FS;

/* USER CODE BEGIN PV */

bool g_runPinTest = true;
uint32_t g_audioTest = 0;
uint32_t g_blinkDelay = 1000;


/* USER CODE END PV */

void SystemClock_Config(void);
static void MX_GPIO_Init(void);
static void MX_USART1_UART_Init(void);
/* USER CODE BEGIN 0 */

void PrintUart(const char * text) {
	HAL_UART_Transmit(&huart1, (const uint8_t *)text, strlen(text), 100);
}

void PrintfUart(const char * format, ...) {
	char buffer[128];
	va_list args;
	va_start(args, format);
	vsnprintf(buffer, sizeof(buffer), format, args);
	va_end(args);
	PrintUart(buffer);
}

char UartInput(void) {
	uint8_t data = 0;
	HAL_UART_Receive(&huart1, &data, 1, 1);
	return data;
}

void TestPortPinsHigh(bool * highOk, GPIO_TypeDef * gpioPort, uint32_t testMask) {
	GPIO_InitTypeDef GPIO_InitStruct = {0};
	for (uint32_t i = 0; i < 16; i++) {
		GPIO_InitStruct.Pin = 1 << i;
		if (!(GPIO_InitStruct.Pin & testMask)) {
			continue;
		}
		GPIO_InitStruct.Mode = GPIO_MODE_INPUT;
		GPIO_InitStruct.Pull = GPIO_PULLUP;
		GPIO_InitStruct.Speed = GPIO_SPEED_FREQ_LOW;
		HAL_GPIO_Init(gpioPort, &GPIO_InitStruct);
		HAL_Delay(1);
		GPIO_PinState pinState = HAL_GPIO_ReadPin(gpioPort, 1 << i);
		if (pinState == GPIO_PIN_SET) {
			highOk[i] = true;
		}
		GPIO_InitStruct.Pull = GPIO_PULLDOWN;
		HAL_GPIO_Init(gpioPort, &GPIO_InitStruct);
	}
}

void TestPortPinsLow(bool * lowOk, GPIO_TypeDef * gpioPort, uint32_t testMask) {
	GPIO_InitTypeDef GPIO_InitStruct = {0};
	for (uint32_t i = 0; i < 16; i++) {
		GPIO_InitStruct.Pin = 1 << i;
		if (!(GPIO_InitStruct.Pin & testMask)) {
			continue;
		}
		GPIO_InitStruct.Mode = GPIO_MODE_INPUT;
		GPIO_InitStruct.Pull = GPIO_PULLDOWN;
		GPIO_InitStruct.Speed = GPIO_SPEED_FREQ_LOW;
		HAL_GPIO_Init(gpioPort, &GPIO_InitStruct);
		HAL_Delay(1);
		GPIO_PinState pinState = HAL_GPIO_ReadPin(gpioPort, 1 << i);
		if (pinState == GPIO_PIN_RESET) {
			lowOk[i] = true;
		}
		GPIO_InitStruct.Pull = GPIO_PULLUP;
		HAL_GPIO_Init(gpioPort, &GPIO_InitStruct);
	}
}


void TestAllPinInterconnects(void) {
	const uint32_t testMasks[4] = {0xF9FF, 0xFFFF, 0xFFFF, 0x4};
	GPIO_InitTypeDef GPIO_InitStruct = {0};

	//High test
	GPIO_InitStruct.Pin = testMasks[0];
	GPIO_InitStruct.Mode = GPIO_MODE_INPUT;
	GPIO_InitStruct.Pull = GPIO_PULLDOWN;
	GPIO_InitStruct.Speed = GPIO_SPEED_FREQ_LOW;
	HAL_GPIO_Init(GPIOA, &GPIO_InitStruct);
	GPIO_InitStruct.Pin = testMasks[1];
	HAL_GPIO_Init(GPIOB, &GPIO_InitStruct);
	GPIO_InitStruct.Pin = testMasks[2];
	HAL_GPIO_Init(GPIOC, &GPIO_InitStruct);
	GPIO_InitStruct.Pin = testMasks[3];
	HAL_GPIO_Init(GPIOD, &GPIO_InitStruct);
	/*We do not test pins GPIOH, they are connected to the crystal, and if they would
	  not work, we could not run the program anyway.
	*/
	bool highOk[64] = {false};
	TestPortPinsHigh(highOk + 0,  GPIOA, testMasks[0]);
	TestPortPinsHigh(highOk + 16, GPIOB, testMasks[1]);
	TestPortPinsHigh(highOk + 32, GPIOC, testMasks[2]);
	TestPortPinsHigh(highOk + 48, GPIOD, testMasks[3]);

	//Low test
	GPIO_InitStruct.Pin = testMasks[0];
	GPIO_InitStruct.Mode = GPIO_MODE_INPUT;
	GPIO_InitStruct.Pull = GPIO_PULLUP;
	GPIO_InitStruct.Speed = GPIO_SPEED_FREQ_LOW;
	HAL_GPIO_Init(GPIOA, &GPIO_InitStruct);
	GPIO_InitStruct.Pin = testMasks[1];
	HAL_GPIO_Init(GPIOB, &GPIO_InitStruct);
	GPIO_InitStruct.Pin = testMasks[2];
	HAL_GPIO_Init(GPIOC, &GPIO_InitStruct);
	GPIO_InitStruct.Pin = testMasks[3];
	HAL_GPIO_Init(GPIOD, &GPIO_InitStruct);
	bool lowOk[64] = {false};
	TestPortPinsLow(lowOk + 0,  GPIOA, testMasks[0]);
	TestPortPinsLow(lowOk + 16, GPIOB, testMasks[1]);
	TestPortPinsLow(lowOk + 32, GPIOC, testMasks[2]);
	TestPortPinsLow(lowOk + 48, GPIOD, testMasks[3]);

	//Restore pins for printing the results
	MX_GPIO_Init();
	MX_USART1_UART_Init();
	for (uint32_t i = 0; i < sizeof(highOk); i++) {
		uint8_t port = i / 16;
		uint8_t pin = i % 16;

		char portChar = 'A' + port;
		if (testMasks[port] & (1 << pin)) {
			const char * result = "?";
			if (highOk[i] && lowOk[i]) {
				result = "ok";
			} else if (lowOk[i] == false) {
				result = "no low";
			} else if (highOk[i] == false) {
				result = "no high";
			} else {
				result = "error - no control";
			}
			PrintfUart("Port%c%u -> %s\r\n", portChar, pin, result);
		}
	}
}

void LedLine(uint32_t pattern) {
	//PB1 is not used as output
	pattern = ((pattern & 0xFFFE) << 1) | (pattern & 1);
	pattern |= (~(pattern << 16)) & 0xFFFD0000;
	//high bits clear, low bits set
	GPIOB->BSRR = pattern;
}

void LedLineEqual(uint8_t color) {
	LedLine((color << 0) | (color << 3) | (color << 6) | (color << 9) | (color << 12));
}

void LedLineSelect(uint8_t line) {
	uint32_t bit = 1 << line;
	uint32_t pattern = bit | (0x1F0000 & ~(bit << 16));
	GPIOC->BSRR = pattern;
}

//See https://stm32f4-discovery.net/2017/04/tutorial-jump-system-memory-software-stm32/
void JumpDfu(void) {
	uint32_t dfuStart = 0x1FFF0000;
	PrintUart("Directly jump to the DFU bootloader\r\n");
	//first all peripheral clocks should be disabled
	McuStartOtherProgram((void *)dfuStart, false); //usually does not return
}

void AudioOutputAnalog(void) {
	__HAL_RCC_GPIOA_CLK_ENABLE();
	GPIO_InitTypeDef GPIO_InitStruct = {0};
	GPIO_InitStruct.Pin = Dac1_Pin;
	GPIO_InitStruct.Mode = GPIO_MODE_ANALOG;
	GPIO_InitStruct.Pull = GPIO_NOPULL;
	GPIO_InitStruct.Speed = GPIO_SPEED_FREQ_LOW;
	HAL_GPIO_Init(Dac1_GPIO_Port, &GPIO_InitStruct);
}

void AudioOutputEnable(void) {
	__HAL_RCC_GPIOA_CLK_ENABLE();
	GPIO_InitTypeDef GPIO_InitStruct = {0};
	GPIO_InitStruct.Pin = AudioOn_Pin;
	GPIO_InitStruct.Mode = GPIO_MODE_OUTPUT_PP;
	GPIO_InitStruct.Pull = GPIO_NOPULL;
	GPIO_InitStruct.Speed = GPIO_SPEED_FREQ_LOW;
	HAL_GPIO_Init(AudioOn_GPIO_Port, &GPIO_InitStruct);
	HAL_GPIO_WritePin(AudioOn_GPIO_Port, AudioOn_Pin, GPIO_PIN_RESET);
}

void AudioOutputDisable(void) {
	__HAL_RCC_GPIOA_CLK_ENABLE();
	GPIO_InitTypeDef GPIO_InitStruct = {0};
	GPIO_InitStruct.Pin = AudioOn_Pin;
	GPIO_InitStruct.Mode = GPIO_MODE_OUTPUT_PP;
	GPIO_InitStruct.Pull = GPIO_NOPULL;
	GPIO_InitStruct.Speed = GPIO_SPEED_FREQ_LOW;
	HAL_GPIO_Init(AudioOn_GPIO_Port, &GPIO_InitStruct);
	HAL_GPIO_WritePin(AudioOn_GPIO_Port, AudioOn_Pin, GPIO_PIN_SET);
}

void DacTest(void) {
	AudioOutputAnalog();
	__HAL_RCC_DAC_CLK_ENABLE();
	DAC1->DHR12R1 = 0;
	DAC1->CR = DAC_CR_EN1;
	for (uint32_t i = 0; i < 16; i++) {
		DAC1->DHR12R1 = 0;
		PrintUart("Dac zero\r\n");
		LedLineEqual(LED_R);
		HAL_Delay(2000);

		DAC1->DHR12R1 = 2047;
		PrintUart("Dac 2047\r\n");
		LedLineEqual(LED_G);
		HAL_Delay(2000);

		DAC1->DHR12R1 = 4095;
		PrintUart("Dac 4095\r\n");
		LedLineEqual(LED_B);
		HAL_Delay(2000);
		if (UartInput() != '\0') {
			break;
		}
	}
	DAC1->DHR12R1 = 0;
	PrintUart("Dac test complete\r\n");
}

void DacEqual(void) {
	AudioOutputAnalog();
	AudioOutputEnable();
	__HAL_RCC_DAC_CLK_ENABLE();
	DAC1->DHR12R1 = 0;
	DAC1->CR = DAC_CR_EN1;
	DAC1->DHR12R1 = 2047;
	g_runPinTest = false;
	PrintUart("Dac equal. Pin test disabled\r\n");
}

#define DAC_MAX 4095
#define SINE_VALUES 1000

void AudioStop(void) {
	TIM7->CR1 = 0;
	DMA1_Stream2->CR = 0;
	AudioOutputDisable();
}

void AudioPlay(uint16_t frequency) {
	RAM_SUPPORTS_DMA static uint16_t data[SINE_VALUES];
	float pi2 = (float)M_PI * (float)2.0;
	for (uint32_t i = 0; i < SINE_VALUES; i++) {
		data[i] = ((float)DAC_MAX/2) + ((float)DAC_MAX/2) * sinf((float)i * pi2 / (float)SINE_VALUES);
	}
	PrintUart("Starting sine test\r\n");
	//stop any old transfer
	AudioStop();
	//Enable audio amplifier and outputs
	AudioOutputAnalog();
	AudioOutputEnable();
	//Enable DAC
	__HAL_RCC_DAC_CLK_ENABLE();
	DAC1->DHR12R1 = 0;
	DAC1->CR = DAC_CR_EN1;
	//Enable DMA (Stream 2, Channel 1, triggered by timer 7)
	__HAL_RCC_DMA1_CLK_ENABLE();
	DMA1_Stream2->CR &= ~DMA_SxCR_EN;
	while(DMA1_Stream2->CR & DMA_SxCR_EN); //if a transfer is ongoing, this waits until it ends
	//Memory increment, Circular mode, Read from memory, Memory size = 16 bits, Peripheral size = 16 bits, Priority medium-high, channel 1
	DMA1_Stream2->CR = DMA_SxCR_MINC | DMA_SxCR_CIRC | DMA_SxCR_DIR_0 | DMA_SxCR_MSIZE_0 | DMA_SxCR_PSIZE_0 | DMA_SxCR_PL_1 | DMA_SxCR_CHSEL_0;
	DMA1_Stream2->PAR = (uint32_t)&DAC->DHR12R1;
	DMA1_Stream2->M0AR = (uint32_t)data;
	DMA1_Stream2->NDTR = SINE_VALUES;
	DMA1_Stream2->CR |= DMA_SxCR_EN;
	//Enable timer
	__HAL_RCC_TIM7_CLK_ENABLE();
	TIM7->PSC = 0;
	TIM7->ARR = (F_CPU / (SINE_VALUES * frequency)) - 1;
	TIM7->CNT = 0;
	TIM7->CR2 = 0;
	TIM7->DIER = TIM_DIER_UDE;
	TIM7->EGR = TIM_EGR_UG;
	TIM7->CR1 = TIM_CR1_CEN;
	PrintfUart("%uHz sine test started\r\n", (unsigned int)frequency);
	for (int i = 0; i < 20; i++) {
		//PrintfUart("Tim: %u, cnt: %u, 0x%x, DAC: %u\r\n", (unsigned int)TIM7->CNT, (unsigned int)DMA1_Stream2->NDTR, (unsigned int)DMA1_Stream2->M0AR, (unsigned int)(DAC->DHR12R1));
	}
}

void AudioToggle(void) {
	g_audioTest = (g_audioTest + 1) % 15; //max 14KHz
	if (g_audioTest) {
		AudioPlay(g_audioTest * 100);
	} else {
		AudioStop();
	}
}

void LightSelect(uint8_t mode) {
	GPIO_InitTypeDef GPIO_InitStruct = {0};

	if (mode == 1) { //56kOhm
		GPIO_InitStruct.Pin = LightOut1_Pin;
		GPIO_InitStruct.Mode = GPIO_MODE_OUTPUT_PP;
		GPIO_InitStruct.Pull = GPIO_NOPULL;
		GPIO_InitStruct.Speed = GPIO_SPEED_FREQ_LOW;
		HAL_GPIO_Init(LightOut1_GPIO_Port, &GPIO_InitStruct);
		HAL_GPIO_WritePin(LightOut1_GPIO_Port, LightOut1_Pin, GPIO_PIN_SET);

		GPIO_InitStruct.Pin = LightOut2_Pin;
		GPIO_InitStruct.Mode = GPIO_MODE_ANALOG;
		GPIO_InitStruct.Pull = GPIO_NOPULL;
		GPIO_InitStruct.Speed = GPIO_SPEED_FREQ_LOW;
		HAL_GPIO_Init(LightOut2_GPIO_Port, &GPIO_InitStruct);
	} else if (mode == 2) { //1kOhm
		GPIO_InitStruct.Pin = LightOut1_Pin;
		GPIO_InitStruct.Mode = GPIO_MODE_ANALOG;
		GPIO_InitStruct.Pull = GPIO_NOPULL;
		GPIO_InitStruct.Speed = GPIO_SPEED_FREQ_LOW;
		HAL_GPIO_Init(LightOut1_GPIO_Port, &GPIO_InitStruct);

		GPIO_InitStruct.Pin = LightOut2_Pin;
		GPIO_InitStruct.Mode = GPIO_MODE_OUTPUT_PP;
		GPIO_InitStruct.Pull = GPIO_NOPULL;
		GPIO_InitStruct.Speed = GPIO_SPEED_FREQ_LOW;
		HAL_GPIO_Init(LightOut2_GPIO_Port, &GPIO_InitStruct);
		HAL_GPIO_WritePin(LightOut2_GPIO_Port, LightOut2_Pin, GPIO_PIN_SET);
	} else if (mode == 3) { //1MOhm
		GPIO_InitStruct.Pin = LightOut1_Pin | LightOut2_Pin;
		GPIO_InitStruct.Mode = GPIO_MODE_ANALOG;
		GPIO_InitStruct.Pull = GPIO_NOPULL;
		GPIO_InitStruct.Speed = GPIO_SPEED_FREQ_LOW;
		HAL_GPIO_Init(LightOut1_GPIO_Port, &GPIO_InitStruct);
	}
}

void LightInit(void) {
	__HAL_RCC_GPIOA_CLK_ENABLE();
	GPIO_InitTypeDef GPIO_InitStruct = {0};
	GPIO_InitStruct.Pin = LightIn_Pin;
	GPIO_InitStruct.Mode = GPIO_MODE_ANALOG;
	GPIO_InitStruct.Pull = GPIO_NOPULL;
	GPIO_InitStruct.Speed = GPIO_SPEED_FREQ_LOW;
	HAL_GPIO_Init(LightIn_GPIO_Port, &GPIO_InitStruct);
}

void AnalogTest(void) {
	LightInit();
	AdcInit();
	uint16_t adcBat = AdcGet(18);
	uint16_t vBatMv = 6.6 * 1000.0 * (float)adcBat / (float)4095.0; //vBat has a 1:2 voltage divider. Reference voltage is 3.3V.
	PrintfUart("Vbat: %u -> %umV\r\n", adcBat, vBatMv);

	LightSelect(1);
	HAL_Delay(1);
	uint16_t vLight1 = AdcGet(0);
	PrintfUart("Light1 56kOhm: %u\r\n", vLight1);

	LightSelect(2);
	HAL_Delay(1);
	uint16_t vLight2 = AdcGet(0);
	PrintfUart("Light2  1kOhm: %u\r\n", vLight2);


	LightSelect(3);
	HAL_Delay(1);
	uint16_t vLight3 = AdcGet(0);
	PrintfUart("Light3  1MOhm: %u\r\n", vLight3);

	AdcStop();
}

void LightRead(void) {
	PrintUart("Keys 1-3 to select pull-up.\r\nx: Light LED line.\r\nOther keys exit\r\n");
	bool led = false;
	LedLineEqual(0); //LED light disturb the reading
	LightInit();
	LightSelect(3);
	AdcInit();
	while(1) {
		char input = UartInput();
		if (input == '1') {
			LightSelect(1);
			PrintUart("56kOhm\r\n");
		} else if (input == '2') {
			LightSelect(2);
			PrintUart("1kOhm\r\n");
		} else if (input == '3') {
			LightSelect(3);
			PrintUart("1MOhm\r\n");
		} else if (input == 'x') {
			led = !led;
			if (led) {
				LedLineEqual(LED_R | LED_G | LED_B);
			} else {
				LedLineEqual(0);
			}
		}
		else if (input != '\0') {
			break;
		}
		uint32_t vLight = 0;
		for (uint32_t i = 0; i < 32; i++) {
			vLight += AdcGet(0);
			HAL_Delay(1);
		}
		vLight /= 32;
		PrintfUart("Light: %u\r\n", (uint32_t)vLight);
		HAL_Delay(200);
	}
	AdcStop();
	LightSelect(3);
}

void InfraredTest(void) {
	IrInit();
	IrOn();

	PrintUart("Press any key to exit IR test\r\n");
	bool stateOld = !IrPinSignal();
	while (UartInput() == '\0') {
		bool pinState = !IrPinSignal();
		if (pinState != stateOld) {
			if (pinState == true) {
				PrintUart("IR 1\r\n");
			} else {
				PrintUart("IR 0\r\n");
			}
			stateOld = pinState;
		}
	}
	PrintUart("Test exit\r\n");
	IrOff();
}

void SdCardOn(void) {
	GPIO_InitTypeDef GPIO_InitStruct = {0};
	GPIO_InitStruct.Pin = SdOn_Pin;
	GPIO_InitStruct.Mode = GPIO_MODE_OUTPUT_PP;
	GPIO_InitStruct.Pull = GPIO_NOPULL;
	GPIO_InitStruct.Speed = GPIO_SPEED_FREQ_LOW;
	HAL_GPIO_Init(SdOn_GPIO_Port, &GPIO_InitStruct);
	HAL_GPIO_WritePin(SdOn_GPIO_Port, SdOn_Pin, GPIO_PIN_RESET);

	GPIO_InitStruct.Pin = SdCs_Pin;
	GPIO_InitStruct.Mode = GPIO_MODE_OUTPUT_PP;
	GPIO_InitStruct.Pull = GPIO_NOPULL;
	GPIO_InitStruct.Speed = GPIO_SPEED_FREQ_LOW;
	HAL_GPIO_Init(SdCs_GPIO_Port, &GPIO_InitStruct);
	HAL_GPIO_WritePin(SdCs_GPIO_Port, SdCs_Pin, GPIO_PIN_SET);

	GPIO_InitStruct.Pin = GPIO_PIN_5 | GPIO_PIN_6 | GPIO_PIN_7;
	GPIO_InitStruct.Mode = GPIO_MODE_AF_PP;
	GPIO_InitStruct.Pull = GPIO_NOPULL;
	GPIO_InitStruct.Speed = GPIO_SPEED_FREQ_MEDIUM;
	GPIO_InitStruct.Alternate = GPIO_AF5_SPI1;
	HAL_GPIO_Init(GPIOA, &GPIO_InitStruct);

	__HAL_RCC_SPI1_CLK_ENABLE();
	SPI1->CR1 = 0;
	SPI1->CR1 = SPI_CR1_MSTR | SPI_BAUDRATEPRESCALER_64 | SPI_CR1_SSM | SPI_CR1_SSI;
	SPI1->CR2 = 0;
	SPI1->CR1 |= SPI_CR1_SPE;
}

void SdChipSelect(bool selected) {
	GPIO_PinState state = GPIO_PIN_SET;
	if (selected) {
		state = GPIO_PIN_RESET;
	}
	HAL_GPIO_WritePin(SdCs_GPIO_Port, SdCs_Pin, state);
}

void SdTransferPolling(const uint8_t * dataOut, uint8_t * dataIn, size_t len, uint8_t /*chipSelect*/, bool resetChipSelect) {
	SdChipSelect(true);
	SpiGenericPolling(SPI1, dataOut, dataIn, len);
	if (resetChipSelect) {
		SdChipSelect(false);
	}
}

void SdCardOff(void) {
	GPIO_InitTypeDef GPIO_InitStruct = {0};

	GPIO_InitStruct.Pin = SdCs_Pin;
	GPIO_InitStruct.Mode = GPIO_MODE_INPUT;
	GPIO_InitStruct.Pull = GPIO_NOPULL;
	GPIO_InitStruct.Speed = GPIO_SPEED_FREQ_LOW;
	HAL_GPIO_Init(SdCs_GPIO_Port, &GPIO_InitStruct);

	GPIO_InitStruct.Pin = SdOn_Pin;
	GPIO_InitStruct.Mode = GPIO_MODE_INPUT;
	GPIO_InitStruct.Pull = GPIO_NOPULL;
	GPIO_InitStruct.Speed = GPIO_SPEED_FREQ_LOW;
	HAL_GPIO_Init(SdOn_GPIO_Port, &GPIO_InitStruct);

	__HAL_RCC_SPI1_CLK_DISABLE();
}

void SdCardTest(void) {
	PrintUart("SD card test\r\n");
	SdCardOn();
	uint32_t result = SdmmcInit(&SdTransferPolling, 0);
	if (result == 0) {
		uint32_t cap = SdmmcCapacity();
		cap /= (2 * 1024); //blocks -> MiB
		PrintfUart("SD card working, %uMiB\r\n", (unsigned int)cap);
	} else if (result == 1) {
		PrintUart("SD card has errors on init\r\n");
	} else if (result == 2) {
		PrintUart("SD card not compatible\r\n");
	} else {
		PrintUart("Internal error\r\n");
	}
	SdCardOff();
}

void SwdTest(void) {
	PrintUart("SWD test. Press any key to exit\r\n");
	GPIO_InitTypeDef GPIO_InitStruct = {0};
	GPIO_InitStruct.Pin = GPIO_PIN_14 | GPIO_PIN_13;
	GPIO_InitStruct.Mode = GPIO_MODE_INPUT;
	GPIO_InitStruct.Pull = GPIO_NOPULL;
	GPIO_InitStruct.Speed = GPIO_SPEED_FREQ_LOW;
	HAL_GPIO_Init(GPIOA, &GPIO_InitStruct);

	bool ignoreDataToggle = false;

	GPIO_PinState stateOldClk = HAL_GPIO_ReadPin(GPIOA, GPIO_PIN_14);
	GPIO_PinState stateOldData = HAL_GPIO_ReadPin(GPIOA, GPIO_PIN_13);
	PrintfUart("Clk %u, data %u\r\n", (unsigned int)stateOldClk, (unsigned int)stateOldData);
	while (UartInput() == '\0') {
		GPIO_PinState stateClk = HAL_GPIO_ReadPin(GPIOA, GPIO_PIN_14);
		GPIO_PinState stateData = HAL_GPIO_ReadPin(GPIOA, GPIO_PIN_13);
		if (stateClk != stateOldClk) {
			if (stateClk == GPIO_PIN_SET) {
				PrintUart("Clk 1\r\n");
			} else {
				PrintUart("Clk 0\r\n");
			}
		}
		if (ignoreDataToggle) {
			continue;
		}
		if (stateData != stateOldData) {
			if (stateData == GPIO_PIN_SET) {
				PrintUart("Data 1\r\n");
			} else {
				PrintUart("Data 0\r\n");
			}
		}
		stateOldData = stateData;
		stateOldClk = stateClk;
	}
	PrintUart("Test exit\r\nSet to alternate function SWD? Y/n");
	char c;
	while ((c = UartInput()) == '\0');
	PrintUart("\r\n");
	if ((c == 'y') || (c == 'Y') || (c == '\r')) {
		GPIO_InitStruct.Pin = GPIO_PIN_14 | GPIO_PIN_13;
		GPIO_InitStruct.Mode = GPIO_MODE_AF_PP;
		GPIO_InitStruct.Pull = GPIO_NOPULL;
		GPIO_InitStruct.Alternate = GPIO_AF0_SWJ;
		GPIO_InitStruct.Speed = GPIO_SPEED_FREQ_MEDIUM;
		HAL_GPIO_Init(GPIOA, &GPIO_InitStruct);
		PrintUart("\r\nSet. Disabling pin test to keep the setting\r\n");
		PrintUart("1MHz frequency seems to work well, the default 1.5MHz ... 2.5MHz not\r\n");
		g_runPinTest = false;
	}
}

void CheckUserInput(void) {
	char input = UartInput();
	switch (input) {
		case 'a': AudioToggle(); break;
		case 'b': JumpDfu(); break;
		case 'd': DacTest(); break;
		case 'e': DacEqual(); break;
		case 'i': InfraredTest(); break;
		case 'l': LightRead(); break;
		case 'p': g_runPinTest = !g_runPinTest; break;
		case 'r': NVIC_SystemReset(); break;
		case 's': SdCardTest(); break;
		case 'u': AnalogTest(); break;
		case 'w': SwdTest(); break;
		case '1': LedLineSelect(0); break;
		case '2': LedLineSelect(1); break;
		case '3': LedLineSelect(2); break;
		case '4': LedLineSelect(3); break;
		case '5': LedLineSelect(4); break;
		case '-': if (g_blinkDelay < 10000) {
			          g_blinkDelay *= 2;
		          };
		          break;
		case '+': if (g_blinkDelay > 100) {
			          g_blinkDelay /= 2;
		          };
		          break;
	}
}

void AllLedFlash(void) {
	uint32_t colors[3] = {LED_R, LED_G, LED_B};
	for (uint32_t colorIdx = 0; colorIdx < 3; colorIdx++) {
		uint32_t color = colors[colorIdx];
		for (uint32_t line = 0; line < 5; line++) {
			LedLineSelect(line);
			for (uint32_t index = 0; index < 15; index += 3) {
				LedLine(color << index);
				HAL_Delay(50);
			}
		}
	}
}

/* USER CODE END 0 */

/**
  * @brief  The application entry point.
  * @retval int
  */
int main(void)
{
  /* MCU Configuration--------------------------------------------------------*/

  /* Reset of all peripherals, Initializes the Flash interface and the Systick. */
  HAL_Init();

  /* Configure the system clock */
  SystemClock_Config();

  /* Initialize all configured peripherals */
  MX_GPIO_Init();
  MX_USART1_UART_Init();
  /* Infinite loop */
	/* USER CODE BEGIN WHILE */
	LedLineSelect(4);
	HAL_Delay(10); //to sync the UART (no strange chars on the terminal)
	PrintUart(">>>>>>>>Hello World<<<<<<<<\r\n");
	while (1)
	{
		HAL_GPIO_WritePin(Line5_GPIO_Port, Line5_Pin, GPIO_PIN_SET);
		LedLineEqual(LED_R);
		CheckUserInput();
		HAL_Delay(g_blinkDelay);
		PrintUart("a: Audio output test\r\n");
		PrintUart("b: Jump to bootloader\r\n");
		PrintUart("d: DAC test\r\n");
		PrintUart("e: DAC equal\r\n");
		PrintUart("i: Infrared test\r\n");
		PrintUart("l: Ligh read test\r\n");
		PrintUart("p: Toggle pin test\r\n");
		PrintUart("r: Reboot\r\n");
		PrintUart("s: SD card test\r\n");
		PrintUart("u: Read analog\r\n");
		PrintUart("w: SWD pin test\r\n");
		PrintUart("+-: Alter blink delay\r\n");
		PrintUart("1-5: Switch flashing lines\r\n");

		LedLineEqual(LED_G);
		CheckUserInput();
		HAL_Delay(g_blinkDelay);

		LedLineEqual(LED_B);
		CheckUserInput();
		HAL_Delay(g_blinkDelay);

		LedLineEqual(LED_R | LED_G);
		CheckUserInput();
		HAL_Delay(g_blinkDelay);

		LedLineEqual(LED_R | LED_B);
		CheckUserInput();
		HAL_Delay(g_blinkDelay);

		LedLineEqual(LED_G | LED_B);
		CheckUserInput();
		HAL_Delay(g_blinkDelay);

		LedLineEqual(LED_R | LED_G | LED_B);
		CheckUserInput();
		HAL_Delay(g_blinkDelay);

		AllLedFlash();

		if (g_runPinTest) {
			TestAllPinInterconnects();
		}
		/* USER CODE END WHILE */

		/* USER CODE BEGIN 3 */
	}
	/* USER CODE END 3 */
}

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


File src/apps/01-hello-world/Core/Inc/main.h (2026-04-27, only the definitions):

#define Charge_Pin GPIO_PIN_13
#define Charge_GPIO_Port GPIOC
#define Line1_Pin GPIO_PIN_0
#define Line1_GPIO_Port GPIOC
#define Line2_Pin GPIO_PIN_1
#define Line2_GPIO_Port GPIOC
#define Line3_Pin GPIO_PIN_2
#define Line3_GPIO_Port GPIOC
#define Line4_Pin GPIO_PIN_3
#define Line4_GPIO_Port GPIOC
#define LightIn_Pin GPIO_PIN_0
#define LightIn_GPIO_Port GPIOA
#define LightOut1_Pin GPIO_PIN_1
#define LightOut1_GPIO_Port GPIOA
#define LightOut2_Pin GPIO_PIN_2
#define LightOut2_GPIO_Port GPIOA
#define AudioOn_Pin GPIO_PIN_3
#define AudioOn_GPIO_Port GPIOA
#define Dac1_Pin GPIO_PIN_4
#define Dac1_GPIO_Port GPIOA
#define Line5_Pin GPIO_PIN_4
#define Line5_GPIO_Port GPIOC
#define SdCs_Pin GPIO_PIN_5
#define SdCs_GPIO_Port GPIOC
#define G10_Pin GPIO_PIN_0
#define G10_GPIO_Port GPIOB
#define Boot1_Pin GPIO_PIN_1
#define Boot1_GPIO_Port GPIOB
#define B10_Pin GPIO_PIN_2
#define B10_GPIO_Port GPIOB
#define G13_Pin GPIO_PIN_10
#define G13_GPIO_Port GPIOB
#define B13_Pin GPIO_PIN_11
#define B13_GPIO_Port GPIOB
#define R13_Pin GPIO_PIN_12
#define R13_GPIO_Port GPIOB
#define G14_Pin GPIO_PIN_13
#define G14_GPIO_Port GPIOB
#define B14_Pin GPIO_PIN_14
#define B14_GPIO_Port GPIOB
#define R14_Pin GPIO_PIN_15
#define R14_GPIO_Port GPIOB
#define Key2_Pin GPIO_PIN_6
#define Key2_GPIO_Port GPIOC
#define Key3_Pin GPIO_PIN_7
#define Key3_GPIO_Port GPIOC
#define Key4_Pin GPIO_PIN_8
#define Key4_GPIO_Port GPIOC
#define Key5_Pin GPIO_PIN_9
#define Key5_GPIO_Port GPIOC
#define SdOn_Pin GPIO_PIN_8
#define SdOn_GPIO_Port GPIOA
#define PowerOff_Pin GPIO_PIN_15
#define PowerOff_GPIO_Port GPIOA
#define Key6_Pin GPIO_PIN_10
#define Key6_GPIO_Port GPIOC
#define RemoteOn_Pin GPIO_PIN_11
#define RemoteOn_GPIO_Port GPIOC
#define RemoteIn_Pin GPIO_PIN_12
#define RemoteIn_GPIO_Port GPIOC
#define Key1_Pin GPIO_PIN_2
#define Key1_GPIO_Port GPIOD
#define R10_Pin GPIO_PIN_3
#define R10_GPIO_Port GPIOB
#define G11_Pin GPIO_PIN_4
#define G11_GPIO_Port GPIOB
#define B11_Pin GPIO_PIN_5
#define B11_GPIO_Port GPIOB
#define R11_Pin GPIO_PIN_6
#define R11_GPIO_Port GPIOB
#define G12_Pin GPIO_PIN_7
#define G12_GPIO_Port GPIOB
#define B12_Pin GPIO_PIN_8
#define B12_GPIO_Port GPIOB
#define R12_Pin GPIO_PIN_9
#define R12_GPIO_Port GPIOB
#define RAM_SUPPORTS_DMA __attribute__((section(".bssDma"), aligned(4)))
#define RAM_NO_DMA __attribute__((section(".bss"), aligned(4)))

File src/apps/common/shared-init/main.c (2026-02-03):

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
/* Includes ------------------------------------------------------------------*/
#include "main.h"

/* USER CODE BEGIN Includes */

#include <reent.h>
#include <unistd.h>

#include "appInterface.h"
#include "ledspiellib/rs232debug.h"

/* USER CODE END Includes */


void SystemClock_Config(void);
/* USER CODE BEGIN 0 */

__attribute__((weak)) void AppCycle(void)
{


}


//See https://stackoverflow.com/questions/73742774/gcc-arm-none-eabi-11-3-is-not-implemented-and-will-always-fail

int _close_r(struct _reent * ptr, int fd) {
	(void)ptr;
	(void)fd;
	return -1;
}

_ssize_t _read_r(struct _reent * ptr, int fd, void *buf, size_t cnt) {
	(void)ptr;
	(void)fd;
	(void)buf;
	(void)cnt;
	return -1;
}

_ssize_t _write_r(struct _reent * ptr, int fd, const void *buf, size_t cnt) {
	(void)ptr;
	(void)fd;
	(void)buf;
	(void)cnt;
	return -1;
}

int _fstat_r(struct _reent * ptr, int fd, struct stat * pstat) {
	(void)ptr;
	(void)fd;
	(void)pstat;
	return -1;
}

off_t _lseek_r(struct _reent * ptr, int fd, off_t pos, int whence) {
	(void)ptr;
	(void)fd;
	(void)pos;
	(void)whence;
	return -1;
}

int _kill_r(struct _reent * ptr, int pid, int sig) {
	(void)ptr;
	(void)pid;
	(void)sig;
	return -1;
}

int _getpid_r(struct _reent * ptr) {
	(void)ptr;
	return -1;
}

int _stat_r(struct _reent * ptr, const char * file, struct stat * pstat) {
	(void)ptr;
	(void)file;
	(void)pstat;
	return -1;
}

int _isatty_r(struct _reent * ptr, int fd) {
	(void)ptr;
	(void)fd;
	return -1;
}


/* USER CODE END 0 */

/**
  * @brief  The application entry point.
  * @retval int
  */
int main(void)
{
  /* MCU Configuration--------------------------------------------------------*/

  /* Reset of all peripherals, Initializes the Flash interface and the Systick. */
  HAL_Init();

  /* Configure the system clock */
  SystemClock_Config();

  /* Initialize all configured peripherals */

  /* USER CODE BEGIN 2 */

  AppInit();

  /* USER CODE END 2 */

  /* Infinite loop */
  /* USER CODE BEGIN WHILE */
  while (1)
  {
    /* USER CODE END WHILE */

    /* USER CODE BEGIN 3 */
    AppCycle();
  }
  /* USER CODE END 3 */
}

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


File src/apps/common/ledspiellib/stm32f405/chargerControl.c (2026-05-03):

/* Ledspiellib
(c) 2026 by Malte Marwedel

SPDX-License-Identifier:  BSD-3-Clause
*/

#include <stdbool.h>

#include "ledspiellib/chargerControl.h"

#include "main.h"

void ChargerControl(bool on) {
	static bool initDone = false;
	if (!initDone) {
		__HAL_RCC_GPIOC_CLK_ENABLE();
		GPIO_InitTypeDef GPIO_InitStruct = {0};
		GPIO_InitStruct.Pin = Charge_Pin;
		GPIO_InitStruct.Mode = GPIO_MODE_OUTPUT_PP;
		GPIO_InitStruct.Pull = GPIO_NOPULL;
		GPIO_InitStruct.Speed = GPIO_SPEED_FREQ_LOW;
		HAL_GPIO_Init(Charge_GPIO_Port, &GPIO_InitStruct);
	}
	if (on) {
		HAL_GPIO_WritePin(Charge_GPIO_Port, Charge_Pin, GPIO_PIN_SET);
	} else {
		HAL_GPIO_WritePin(Charge_GPIO_Port, Charge_Pin, GPIO_PIN_RESET);
	}
}

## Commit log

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2025-10-14 Simulation: Add SPICE model for power up
    SwitcherCAD III model for enabling the step-up regulator when connecting power.
2025-10-14 Schematic: Add version 1.0, sent to manufacturer
    [bom-1-0.ods, calculations.ods, ledspiel.kicad_pcb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]
2025-11-12 Schematic: Fix RGB LED footprints, fix power up, adjust LED resistor
    Fix the green and blue pins of the LEDs in the schematic to be switched.
    Fix R8 to be too high. Otherwise the power would immediately be switched off again.
    Decrease R87 to increase brightness of D83.
    Schematic version 1.1
    [bom-1-1.ods, ledspiel.kicad_pcb, ledspiel.kicad_sch]
2025-11-21 Common: Add unmodified files from ST
    Taken from
    STM32Cube_FW_F4_V1.28.3
    and
    STM32Cube_FW_F4_V1.25.2
    Each file is under an Apache 2.0 or BSD 3-Clause license. Check each file or folder which one is applied.
2025-11-21 App: Hello World - test everything important
    Provides tests for:
    All LEDs
    All MCU pins
    SD card
    Measure brightness
    Measure battery voltage
    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
2025-12-13 App: hello-world: Add test for SWD debug connection
    Prints the input level. If it toggles while a debugger is connected, the wires work.
    Also allows setting back the pins for debug, as the pin test configures the pins to a mode
    where no debug connection is possible.
2025-12-13 Common: Add Lightweight USB Device Stack library
    This only adds the relevant source files for the STM32F405 from the libusb_stm32 project.
    A stm32_compat.h must be added to use the code.
    Taken from commit 396c2c50ad330b522104d0565525a7350e486fb9.
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2025-12-13 Common: Add ledspiellib
    The shared files are mostly specific for the STM32F405 and the ledspiel PCB.
    These are the files needed for the 02-loader app.
2025-12-13 Common: Shared-init: Add files for using HAL with STM32F405 and the Ledspiel PCB
    Its a mix of CubeMX generated files with own modifications.
2025-12-13 Apps: Add 02-loader project
    This is a DFU loader which allows copying apps into the RAM and then
    executes the app.
    This will allow fast development of the main firmware without using up
    the flash program cycles.
    This project is a modified copy of
    https://github.com/Solartraveler/UniversalboxArm/tree/a2017e5d17217898de555d77526e7ae967745359/src/apps/03-loader
    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
2025-12-13 img: Add a image of the PCB
    SWD and serial debug wires are connected.
2025-12-14 Common: ledspiellib: Add code for SPI, ADC and infrared
    Copied and adjusted from
    https://github.com/Solartraveler/UniversalboxArm/tree/a2017e5d17217898de555d77526e7ae967745359/src/apps/common/boxlib
    For the SPI and ADC, the code is based on the STM32F411 variant.
    The SPI DMA transfer has not been tested (yet).
2025-12-14 App: hello-world: Replace SPI access, ADC, MCU and infrared code by shared code
    The behaviour is the same, just the sources are now shared, cleaning up the project.
    [main.c]
2026-01-08 Apps: 01-hello-world: Fix setting pin for SD card
    The wrong chip select pin was configured. Worked even with the wrong value in place.
    [main.c]
2026-01-08 Apps: 02-loader: Fix USB descriptor length
    Old value was suitable if there is an alternate config in place.
    [loader.c]
2026-01-08 Common: Fix typo in enabling debug prints in SDMMC driver
    [sdmmcAccess.c]
2026-01-08 Common: Ledspiellib: Add 144MHz option, fix setting prescaler, add function for reading µs timestamps
    [mcu.c]
2026-01-08 Common: ledspiellib: Add flash access
    This allows access to the SD/MMC card via SPI1.
    DMA access works.
2026-02-03 Shared-init: Fix linker warnings
    [...]/arm-none-eabi/lib/thumb/v7e-m+fp/hard/libc_nano.a(libc_a-closer.o): in function `_close_r':
    [...]/newlib/libc/reent/closer.c:47:(.text+0xc): warning: _close is not implemented and will always fail
    ... and more more warings like this.
    These were introduced by toolchaing arm-gnu-toolchain-11.3.rel1-x86_64-arm-none-eabi.
    So the warings are there when compiling with the libs provided by Debian 13 and were not there when using Debian 12.
    [main.c]
2026-02-03 Common: ledspiellib: Switch flash access from polling to DMA
    This improves the speed.
2026-02-03 Apps: Add 03-ledspiel
    This is the main firmware.
    However currently the only functionality is reading the SD card over USB,
    and even this is really slow so wait for a long time until the USB drive appears in your OS.
    This is far from being finished.
2026-02-16 Apps: 01-hello-world: Fix audio test
    The audio test only generated a hearable output if DAC test was selected before.
    [main.c]
2026-02-16 Common: Add fatfs lib for reading and writing files
    The code is taken from
    http://elm-chan.org/fsw/ff/00index_e.html version 0.14b.
    diskio.c has been adjusted to use the ledspiellib for reading from the flash (SD card).
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2026-02-18 02-loader: Add watchdog option, clean up code
    If a program specifies a watchdog option, this now enables the IWDG.
    This makes debugging progams which end in an endless loop much easier - no more power cycle needed.
    Also clean up some unused code. It was a leftover from the UniversalboxARM project.
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2026-02-21 Common: Ledspiellib: Add Stack sampler
    A simple way to figure out the maximum stack usage.
2026-02-21 Common: Shared-init: Move stack to CCMRAM, adjust DMA usage for flash access
    As the SRAM1 and SRAM2 are full, the stack is moved to the CCMRAM.
    This should improve the general speed a littple bit as the CCMRAM can be accessed faster by the CPU.
    However it can not be accessed by DMA, so a buffer on the stack can no longer be used in this case.
    Therefore the external flash access (SD card) now needs a static buffer for its DMA transfer.
    This decreases the SD performance a little bit.
    [flash.c]
2026-02-21 03-ledspiel: Playing an mp3 works
    After startup, the first mp3 file in the folder 01 from the SD card is played once.
    The playing the file shows 11% of the time is unused for waiting.
    Therefore about 42.7MHz is the minimum CPU frequency needed when executing from RAM
    and playing back a variable bit rate file with ~189kbit/s.
    This could be improved by disabling the stack sampler, executing from flash or
    remapping the RAM so the I- and D-BUS instead of the S-BUS are used.
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2026-03-08 CI: Fix artifact path, switch Utilities and Apps build order
    The switch allows to use the utilities in the Apps build step.
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2026-03-24 ledspiellib: Fix flash chip select
    If a hardware (ISR or DMA) is setting other pins on the GPIO, no read-modify-write is allowed by any other
    parts of the software as otherwise modifications of the hardware is overwritten to the previous state.
    [flash.c]
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2026-04-03 common: algorithm: Change return value of FilesystemMount
    Having an uint8_t instead of a bool as return value allows to show a more useful
    error message. So the user knows why the mounting has failed.
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2026-04-22 schematic: Update BOM
    Add the handle. This will protect the switches in the case of a drop.
    [bom-1-1.ods]
2026-04-23 shared-init: Fix variables with the cached attribute were not zero initialized
    Variables which are zero initialized may not be placed in the .ccmram section, which
    is not initialized. The .bss section is in the .ccmram too, at least for the *.RAM.ld linker script.
    [main.h]
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2026-04-27 case: Add top drilling or milling operations
    Modifying the case can be done with a drill or mill.
    The design was tested with a CNC mill.
    .FCStd: FreeCAD file -> exported to .step
    .heeks: HeeksCAD file, imported from .step, exported to .ngc
    .ngc: Milling path for a 2mm end mill. Milled with Candle2.
    The version of FreeCAD used, is 1.1.0.
    [top-drill-v1.FCStd]
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2026-05-03 03-ledspiel: Support charging, fix keys
    Key input works as intended.
    Watchdog is stared by default.
    Temperature and voltages can be read.
    Charger starts if conditions are right.
    Matrix adjusts its brighness according to the surrounding brightness.
    Playback stops after 4 songs if no user input is present.
    [adc.c, ledspiel.c]
2026-05-12 ledspiellib: Fix reading keys, support power down
    One key was setting two of the input bits. Also the bit order was
    not according to the documentation.
    [keyInput.c]
2026-05-12 03-ledspiel: Support auto power off, detect empty battery
    Also do not retry to charge after just 1s if an error is detected,
    in this case the waiting time is now 1min. In the case of an USB
    disconnect, the next charging is tried after 5s.
    It turns out there should have been another voltage measurement wire
    on the PCB to better detect if USB power is available.
    Now all minimal required featues for a useful toy are implemented.
    USB and infrared are still missing.
    [ledspiel.c]
2026-05-19 03-ledspiel: Sort files by name, measure CPU usage, reduce power consumption
    Power consumption is reduced by executing wfi, but most of the time the CPU
    is at 98% load anyway.
    Filenames should be different within the first 3 characters, otherwise
    the wrong file can be selected.
    After selecting a new folder, the first animation is only played once, all others
    are then repeated endlessly. This allows showing the folder name once at the
    beginning.
    [ledspiel.c]
2026-05-21 03-ledspiel: Decrease battery empty detection, enable USB or stop playback by keys
    An empty battery is now needs a measurement of 100mV less than before.
    Pressing the play key 2s now stops playing.
    Pressing the animation and play key for 2s now toggles the USB mode.
    If no mp3 is played, the CPU now is more often in the power saving mode.
    For sorting files qsort has been replaced by bubblesort, otherwise the program
    would not fit into the RAM anylonger.
    [ledspiel.c]
2026-05-22 ledspiellib: Add pulldown to rs232 debug
    This fixes random char reception if no debug cable is connected.
    [rs232debug.c]
2026-05-22 03-ledspiel: Avoid random debug char reception
    Previous there were sometimes debug functions called.
    The important part is the update of the used ledspiellib of the previous commit.
    [ledspiel.c]
2026-05-26 case: Add drill path for speaker
    Easiest drilled with a 3mm drill.
    If placed right, the potentiometer for the audio volume can be adjusted with
    a screwdriver through one of the holes.
    [speaker-drill-v1.FCStd]
2026-09-05 Schematic: Values for lower power variant with 3.1V
    Saves about 10% of power, resulting in a longer battery life.
    Also fix a comment. C3 and C4 are optional for Y2, not C1 and C2.
    [bom-1-1.ods, calculations.ods]
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2026-09-16 03-ledspiel: Support writing over USB to the SD card
    Bugfixes:
    Writing now properly dequeues the data from the endpoint.
    Opening the device multiple times no longer results in an endpoint configuration failure.
    Fixing bulk reset command expecting a wrong length.
    Fixing bulk reset not setting up the free hardware FIFO again.
    Fixing serial debug commands for StorageCycle were ignored.
    The device is now writeable by default (enabling writing later was ignored too).
    Adding benchmark results.
    Double buffering is still untested.
    [ledspiel.c, usbMsc.c]
2026-10-02 03-ledspiel: Fix USB access 4GiB limit
    Would have overflown for cards with > 4GiB of storage.
    [usbMsc.c]
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

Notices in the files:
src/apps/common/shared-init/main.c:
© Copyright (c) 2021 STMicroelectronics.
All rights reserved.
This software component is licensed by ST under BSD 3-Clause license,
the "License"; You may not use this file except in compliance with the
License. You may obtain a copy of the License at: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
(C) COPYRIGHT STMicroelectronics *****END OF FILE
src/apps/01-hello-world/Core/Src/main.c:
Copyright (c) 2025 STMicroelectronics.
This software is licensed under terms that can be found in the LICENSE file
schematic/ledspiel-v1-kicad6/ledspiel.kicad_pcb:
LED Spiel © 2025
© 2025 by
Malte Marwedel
